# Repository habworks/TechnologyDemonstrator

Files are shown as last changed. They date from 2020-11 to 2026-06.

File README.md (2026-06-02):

# Hab's Technology Demonstrator
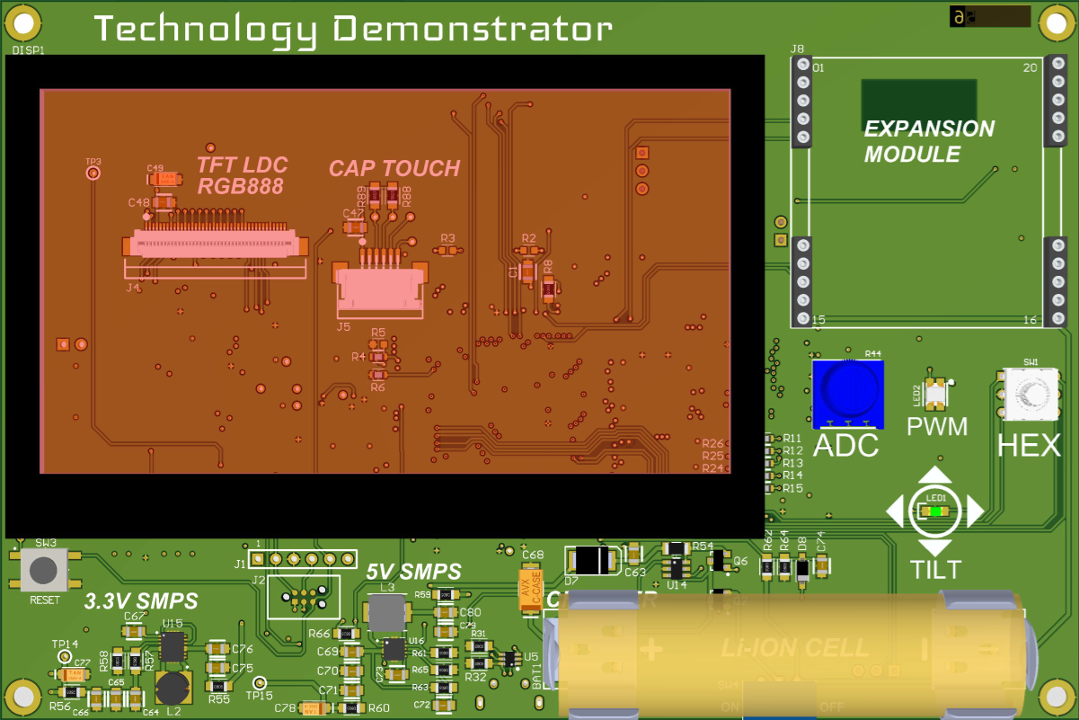
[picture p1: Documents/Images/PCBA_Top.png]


Developed as a sales tool to assist me in selling my design capabilites this is a catch-all project.  It includes a little of everything.  Based on an ARM Cortex M7 and the Touch GFX graphics library the project demonstrates my hardware and firmware design capabilites.  Devloped during the COVID lock-in I hope you enjoy it, see the value, and invite me to work on your project:<br>

## Quick Visual Links:
See [Block Diagram](https://imrengineeringcom-my.sharepoint.com/:p:/g/personal/hab_collector_imrengineering_com/IQBJmAEbv2q8TZ0ApIJ88drxAbf0ilMzcAGDfjFYzenVswI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) from IMR Cloud<br>
See [Schematics PCB 3D](https://imrengineeringcom-my.sharepoint.com/:b:/g/personal/hab_collector_imrengineering_com/IQCkbXLIxkKmTaa8k9nujfb7AQS4M2PV1brDCnOEc579SEw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) from IMR Cloud<br>

## Project Features:
Hardware:
- ARM Cortex M7 uC
- Grapical Touch Display 
- SDRAM
- ADC & DAC
- SMPS
- Accelerometer
- uSD
- Battery Power and charging
- I2C, SPI, USB, UART
 
Firmware:
- FreeRTOS + CMSIS
- Grpahical User Interface
- UI Touch Interface 242x480  
- Custom Audio Playback
- Custom Driver Development  
 
Hardware and Firmware 100% designed by:<br>
Hab Collector<br>
Principal Engineer<br>
IMR Engineering, LLC<br>

## Project Folders:
| Folder | Description |
|---|---|
| Demo | URL to demo - just use the link provided above|
| Documents | Block Diagram and misc|
| AppFirmware/TD_AppFirmware| Application Firmware|
| AppFirmware/ESP8266| WIFI Module|
| Firmware| Test Firmware|
| Hardware | Hardware Design in Altium: Schematics, PCB, Gerber|

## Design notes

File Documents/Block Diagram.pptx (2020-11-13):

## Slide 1

MICRO SD DRIVE

D[0:3], CLK, CMD
SD DETECT

MEMORY

STM32F746I
MEMORY

SDRAM 4M X 32

A[0:11], D[0:15],
B[0:1], NBL[0:1],
SDCKE0, SDCLK, SDNCAS,
SDNE0, SDRAS, SDNWE

D[0:3], CLK, CMD,

SD DETECT

ADDR, DATA, CTL

QUAD SPI FLASH

IO[0:3], CLK, NCS

IO[0:3], CLK, NCS

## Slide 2

LCD TOUCH

I2C#

LCD & TOUCH

STM32F746I
LCD & TOUCH

TFT LCD RGB888

RED[0:7]
GREEN[0:7]
BLUE[0:7]
CLK
DE
VSYNC
HSYNC

SDA, SCLK

IRQ, RESET

R, G, B, CTL

BACK LIGHT PWM

DISPLAY ON /OFF

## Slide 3

USB OTG FS

DP, DM
VBUS, SOF, ID, PWR

USB & SERIAL

STM32F746I
USB
SERIAL

UART: WIFI ESP8266

UART#

DP, DM

VBUS, SOF, ID, PWR

TX, RX

UART: DEBUG

UART#

UART: EXPANSION

UART#

TX, RX

TX, RX

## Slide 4

AUDIO VOL TRIM POT

I2C#

I2C & SPI

STM32F746I
I2C
SPI

EXPANSION SLOT

I2C#

SDA, SCLK

SDA, SCLK

ACCELEROMETER

SPI#

EXPANSION SLOT

SPI#

MOSI, MISO, CLK

MOSI, MISO, CLK

CS

CS

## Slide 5

ANALOG SIGNALS

ADC#: BATTERY
ADC#: UI GUI

ADC DAC GPIO

ADC
DAC
GPIO

ADC

ULTRA SONIC

PWR, TRIG, ECHO

AUDIO OUT

AUDIO CIRCUIT

IO

DAC

UI INTERACTIVE

UI LED
UI SWITCH

EXPANSION SLOT

GPIO

GPIO

GPIO

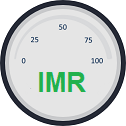
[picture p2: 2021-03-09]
AppFirmware/TD_AppFirmware/TouchGFX/assets/images/IMR_Engineering_Guage.png

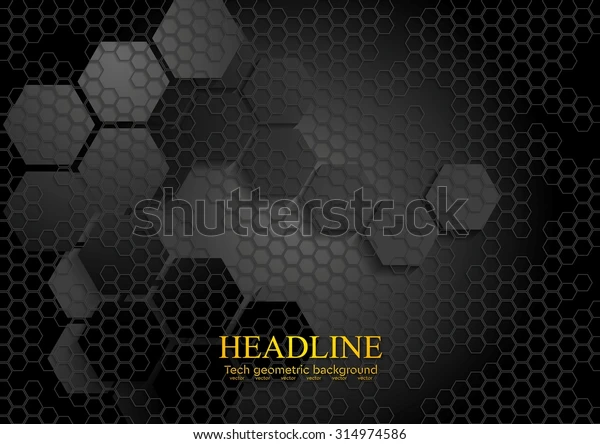
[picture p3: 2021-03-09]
AppFirmware/TD_AppFirmware/TouchGFX/assets/images/Background2.png

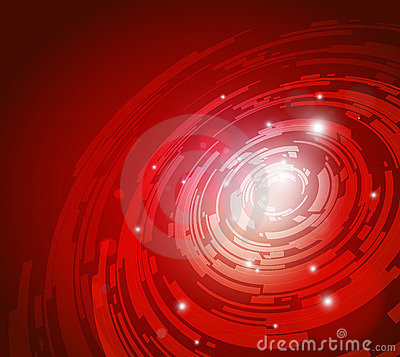
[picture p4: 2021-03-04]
AppFirmware/TD_AppFirmware/TouchGFX/assets/images/DigitalRed3.png

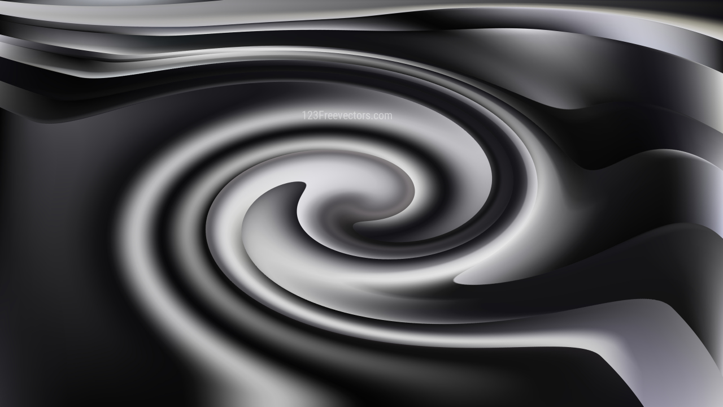
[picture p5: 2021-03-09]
AppFirmware/TD_AppFirmware/TouchGFX/assets/images/Background1.png

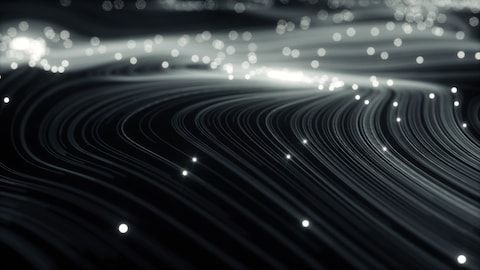
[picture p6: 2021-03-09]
AppFirmware/TD_AppFirmware/TouchGFX/assets/images/MainMenuBG.png

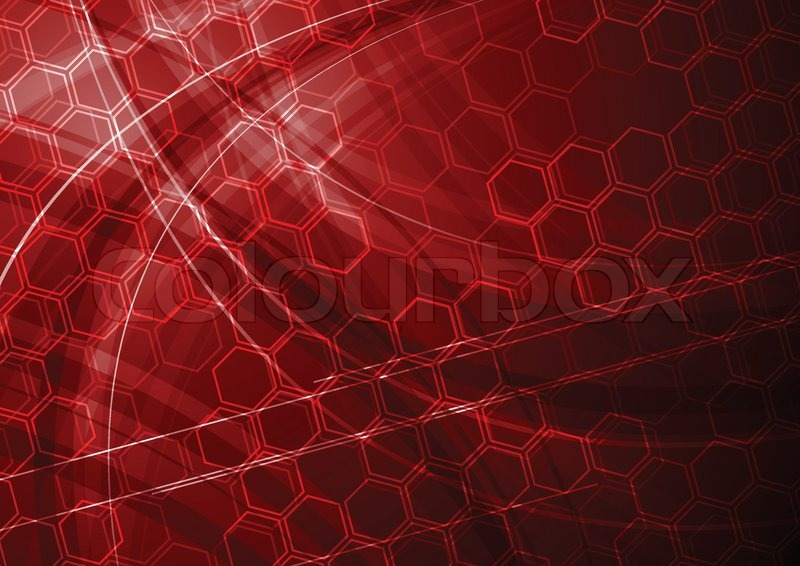
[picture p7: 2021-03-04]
AppFirmware/TD_AppFirmware/TouchGFX/assets/images/DigitalRed2.png

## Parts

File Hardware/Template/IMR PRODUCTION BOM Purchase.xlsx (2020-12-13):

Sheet: Part List Report
 |  | PRODUCTION BOM |  |  | Field=ProjectTitle
 |  | Source Data From: | Field=DataSourceFileName |  | Company Part Number: | Field=DocumentNumber
 |  | Project: | Field=ProjectFileName |  | PCB Revision: | Field=Revision
 |  | Variant: | Field=VariantName |  | Engineer: | Field=Engineer
 |  | Report Date: | Field=ReportDate | Field=ReportTime
 |  | Print Date: | 2020-12-12 | 6:47:49
# | Column=Quantity | Column=LibRef | Column=Description | Column=Designator | Column=MFG | Column=MFG_PN | Column=Supplier 1 | Column=Supplier Part Number 1 | Column=Footprint
1
2
3
Approved |  |  |  |  | Notes |  |  | Total Items in BOM | Field=TotalQuantity

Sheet: Project Information
Project Full Path | Field=ProjectFullPath
Project Filename | Field=ProjectFileName
Variant Name | Field=VariantName
Data-Source Filename | Field=DataSourceFileName
Data-Source Full Path | Field=DataSourceFullPath
Title | Field=Title
Total Quantity | Field=TotalQuantity
Report Time | Field=ReportTime
Report Date | Field=ReportDate
Report Date & Tine | Field=ReportDateTime
Output Name | Field=OutputName
Output Type | Field=OutputType
Output Generator Name | Field=GeneratorName
Output Generator Description | Field=GeneratorDescription
Total Actual Price | Field=TotalActualPrice
Total Target Price | Field=TotalTargetPrice

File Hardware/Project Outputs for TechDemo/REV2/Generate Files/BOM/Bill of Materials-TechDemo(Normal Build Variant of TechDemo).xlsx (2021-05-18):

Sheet: Part List Report
 |  | PRODUCTION BOM |  |  | IMR Technology Demonstrator
 |  | Source Data From: | TechDemo.PrjPcb |  | Company Part Number: | IMR_004
 |  | Project: | TechDemo.PrjPcb |  | PCB Revision: | 2
 |  | Variant: | Normal Build Variant of TechDemo |  | Engineer: | H. Collector
 |  | Report Date: | 4/17/2021 | 1:39 PM
 |  | Print Date: | 2021-04-17 | 13:39:05
# | Quantity | LibRef | Description | Designator | MFG | MFG_PN | Supplier 1 | Supplier Part Number 1 | Footprint
1 | 1 | CONN_BATTERY_18650 | BATTERY CONTACT CLP 18650 PC PIN (NOTE: QTY x2) | BAT1 | Keystone Electronics | 54 | Digi-Key | 36-54-ND | CONN_BATTERY_18650
2 | 13 | CAP_2.2UF_50V_0805 | CAP CER 2.2UF 50V X7R 0805 | C1, C22, C23, C24, C25, C26, C27, C28, C29, C61, C62, C63, C74 | Taiyo Yuden | UMK212BB7225MG-T | Digi-Key | 587-4963-1-ND | CAP_0805
3 | 2 | CAP_4.7PF_50V_0603 | CAP CER 4.7PF 50V C0G/NPO 0603 | C4, C5 | Yageo | CC0603CRNPO9BN4R7 | Digi-Key | 311-1740-1-ND | CAP_0603
4 | 28 | CAP_0.1UF_50V_0603 | CAP CER 0.1UF 50V X7R 0603 | C6, C7, C8, C9, C10, C11, C12, C13, C14, C15, C16, C17, C18, C19, C20, C21, C32, C33, C34, C35, C36, C37, C38, C39, C40, C41, C42, C43 | Yageo | CC0603KRX7R9BB104 | Digi-Key | 311-1344-1-ND | CAP_0603
5 | 18 | CAP_0.1UF_50V_0805 | CAP CER 0.1UF 50V X7R 0805 | C30, C31, C47, C48, C50, C51, C52, C53, C56, C57, C58, C60, C67, C81, C82, C83, C86, C87 | AVX | 08055C104KAT2A | Digi-Key | 478-1395-1-ND | CAP_0805
6 | 4 | CAP_10UF_10V_0805 | CAP CER 10UF 10V X7R 0805 | C44, C45, C76, C80 | TDK Corporation | C2012X7R1A106K125AC | Digi-Key | 445-6857-1-ND | CAP_0805
7 | 4 | CAP_22UF_10V_TANT | CAP TANT 22UF 20% 10V 1206 | C46, C49, C77, C78 | AVX Corporation | TAJA226M010RNJ | Digi-Key | 478-5798-1-ND | CAP_1206_TANT
8 | 3 | CAP_10UF_50V_1206 | CAP CER 10UF 50V X5R 1206 | C54, C84, C85 | Samsung Electro-Mechanics | CL31A106KBHNNNE | Digi-Key | 1276-2876-1-ND | CAP_1206
9 | 1 | CAP_1.0UF_50V_0805 | CAP CER 1UF 50V X7R 0805 | C55 | Taiyo Yuden | UMK212B7105MGHT | Digi-Key | 587-6375-1-ND | CAP_0805
10 | 3 | CAP_22UF_16V_TANT | CAP TANT 22UF 20% 16V 2312, CAP TANT 22UF 10% 16V 2312 | C59, C68, C88 | AVX Corporation | TRJC226K016RRJ | Digi-Key | 478-11127-1-ND | CAP_2312
11 | 8 | CAP_22UF_6.3V_0805 | CAP CER 22UF 6.3V X5R 0805 | C64, C65, C66, C69, C70, C71, C75, C79 | Samsung Electro-Mechanics | CL21A226KQQNNNE | Digi-Key | 1276-2907-1-ND | CAP_0805
12 | 1 | CAP_18PF_50V_0805 | CAP CER 18PF 50V C0G/NP0 0805 | C72 | Stackpole Electronics Inc | CML0805C0G180JT50V | Digi-Key | 738-CML0805C0G180JT50VCT-ND | CAP_0805
13 | 1 | CAP_18NF_50V_0805 | CAP CER 0.018UF 50V X7R 0805 | C73 | Yageo | CC0805KRX7R9BB183 | Digi-Key | 311-1137-1-ND | CAP_0805
14 | 5 | DIODE_1N4148W-7-F | DIODE GEN PURP 100V 300MA SOD123 | D1, D5, D6, D8, D10 | Diodes Incorporated | 1N4148W-7-F | Digi-Key | 1N4148W-FDICT-ND | SOD123
15 | 2 | DIODE_SCHOTTKY_PMEG3005EGWJ | DIODE SCHOTTKY 30V 500MA SOD123 | D2, D9 | Nexperia USA Inc. | PMEG3005EGWJ | Digi-Key | MBRS2040LT3GOSCT-ND | SOD123
16 | 2 | DIODE_TVS_GSOT03C-G3-08 | TVS DIODE 3.3V 12.3V SOT23 | D3, D4 | Vishay Semiconductor | GSOT03C-G3-08 | Digi-Key | GSOT03C-G3-08GICT-ND | SOT-23
17 | 1 | DIODE_SCHOTTKY_MBRS2040LT3G | DIODE SCHOTTKY 40V 2A SMB | D7 | ON SEMICONDUCTOR | MBRS2040LT3G | Digi-Key | MBRS2040LT3GOSCT-ND | SMB
18 | 1 | MODULE_NHD-4.3-480272EF-ASXV#-CTP | LCD TFT 480X272 HIGH BRIGHT | DISP1 | Newhaven Display Intl | NHD-4.3-480272EF-ASXV#-CTP | DigiKey | NHD-4.3-480272EF-ASXV#-CTP-ND | NHD_NHD-4.3-480272EF-ASXV#-CTP
19 | 5 | FERRITE_BLM21AG102SN1D | FERRITE, 1KOHM AT 100MHZ, 220MA, .450DCR | FB1, FB2, FB3, FB4, FB5 | MURATA | BLM21AG102SN1D | Digi-Key | 490-1041-1-ND | RES_0805
20 | 1 | CONN_HIROSE_DM3BT-DSF-PEJS | CONN MICRO SD CARD PUSH-PUSH R/A | J3 | Hirose Electric Co Ltd | DM3BT-DSF-PEJS | Digi-Key | HR1942CT-ND | HRS_DM3BT-DSF-PEJS
21 | 1 | CONN_MOLEX_0512964033 | CONN FFC BOTTOM 40POS 0.50MM R/A | J4 | Molex | 0512964033 | Digi-Key | WM11237CT-ND | CONN_MOLEX_0512964033
22 | 1 | CONN_MOLEX_0522070660 | CONN FPC TOP 6POS 1.00MM R/A | J5 | Molex | 0522070660 | Digi-Key | WM10939CT-ND | CONN_MOLEX_0522070660
23 | 1 | CONN_USB_MOLEX_0475900001 | CONN RCPT MICRO USB AB 5P SMD RA | J6 | Molex | 0475900001 | Digi-Key | WM17144CT-ND | MICRO_USB_AB_MOLEX_0475900001
24 | 2 | CONN_3P_SINGLE_ROW | CONN HEADER VERT 3POS 2.54MM | J7, J11 | Sullins Connector Solutions | PREC003SFAN-RC | Digi-Key | S1212EC-03-ND | HDR_1X3_100MILL
25 | 1 | CONN_TD_EXPANSION_MODULE | CONN HEADER VERT 5POS 2.54MM (NOTE: QTY x4) | J8 | Sullins Connector Solutions | PPTC051LFBN-RC | Digi-Key | S6103-ND | CONN_EXPANSION_BOARD
26 | 1 | CONN_2P_SINGLE_ROW | CONN HEADER VERT 2POS 2.54MM | J10 | Sullins Connector Solutions | PREC002SFAN-RC | Digi-Key | S1212EC-02-ND | HDR_1X2_100MILL
27 | 1 | INDUCTOR_LPS4018-472MRC | SHIELDED POWER INDUCTORS, 4.7UH | L1 | COILCRAFT | LPS4018-472MRC | Digi-Key | 2457-LPS4018-472MRC-ND | LPS4018
28 | 1 | INDUCTOR_SDR0403-1R0ML | FIXED IND 1UH 3.8A 33 MOHM SMD | L2 | Bourns Inc. | SDR0403-1R0ML | Digi-Key | SDR0403-1R0MLCT-ND | IND_SDR0403
29 | 1 | INDUCTOR_IHLP2020BZER1R0M01 | FIXED IND 1UH 3.8A 33 MOHM SMD | L3 | Bourns Inc. | IHLP2020BZER1R0M01 | Digi-Key | 541-1087-1-ND | INDPM5552X200N
30 | 1 | DIODE_LED_GREEN_LTST-C170GKT | DIODE, LED GREEN CLEAR SMD | LED1 | Lite-On Inc. | LTST-C170GKT | Digi-Key | 160-1179-1-ND | PMG_LTST-C170GKT
31 | 1 | LED_RED_GREEN_HSMF-A201-A00J1 | LED GREEN/RED CLEAR 4PLCC SMD | LED2 | Broadcom Limited | HSMF-A201-A00J1 | Digi-Key | 516-2491-1-ND | 4PLCC-LED
32 | 3 | MOSFET_PCH_NTR3A30PZT1G | MOSFET P-CH 20V 3A SOT23-3 | Q1, Q2, Q6 | ON Semiconductor | NTR3A30PZT1G | Digi-Key | NTR3A30PZT1GOSCT-ND | SOT-23
33 | 3 | MOSFET_NCH_2N7002-7-F | MOSFET N-CH 60V 115MA SOT23-3 | Q3, Q4, Q5 | Diodes Incorporated | 2N7002-7-F | Digi-Key | 2N7002-FDICT-ND | SOT-23
34 | 1 | RES_200_0805_1/8W_1%_1 | RES SMD 200 OHM 1% 1/8W 0805 | R1 | Yageo | RC0805FR-07200RL | Digi-Key | 311-200CRCT-ND | RES_0805
35 | 1 | RES_10K_0603_1/10W_1% | RES SMD 10K OHM 1% 1/10W 0603 | R4 | Yageo | RC0603FR-0710KL | Digi-Key | 311-10.0KHRCT-ND | RES_0603
36 | 20 | RES_100K_0603_1/10W_1% | RES SMD 100K OHM 1% 1/10W 0603 | R6, R7, R11, R12, R13, R14, R15, R16, R17, R18, R19, R20, R21, R22, R23, R24, R25, R26, R67, R68 | Yageo | RC0603FR-07100KL | Digi-Key | 311-100KHRCT-ND | RES_0603
37 | 10 | RES_0_0805_1/8W | RES SMD 0 OHM JUMPER 1/8W 0805 | R8, R29, R30, R33, R52, R55, R56, R59, R60, R76 | Yageo | RC0805JR-070RL | Digi-Key | 311-0.0ARCT-ND | PMG_RES_0805
38 | 13 | RES_10K_0805_1/4W_1% | RES SMD 10K OHM 1% 1/4W 0805 | R9, R10, R45, R47, R49, R69, R70, R71, R72, R73, R78, R88, R89 | KOA Speer Electronics, Inc. | SG73S2ATTD1002F | Digi-Key | 2019-SG73S2ATTD1002FCT-ND | RES_0805
39 | 24 | RES_100K_0805_1/4W_1% | RES SMD 100K OHM 1% 1/4W 0805 | R27, R34, R35, R36, R37, R40, R41, R42, R43, R46, R48, R50, R51, R61, R64, R65, R66, R74, R75, R79, R80, R81, R82, R85 | KOA Speer Electronics, Inc. | RK73H2ATTD1003F | Digi-Key | 2019-RK73H2ATTD1003FCT-ND | PMG_RES_0805
40 | 1 | RES_5.1_0805_1/8W_1% | RES 5.1 OHM 1% 1/8W 0805 | R28 | Yageo | RC0805FR-075R1L | Digi-Key | YAG3373CT-ND | PMG_RES_0805
41 | 2 | RES_15K_0805_1/8W_1% | RES SMD 15K OHM 1% 1/8W 0805 | R31, R32 | Yageo | RC0805FR-0715KL | Digi-Key | 311-15.0KCRCT-ND | RES_0805
42 | 2 | RES_120_0805_1/4W_1% | RES 120 OHM 1% 1/4W 0805 | R38, R39 | KOA Speer Electronics, Inc. | RK73H2ATTD1200F | Digi-Key | 2019-RK73H2ATTD1200FCT-ND | PMG_RES_0805
43 | 1 | RES_POT_10K_500mW | TRIMMER 10K OHM 0.5W PC PIN TOP | R44 | Bourns Inc. | 3386F-1-103TLF | Digi-Key | 3386F-103TLF-ND | BOURNS_3386F
44 | 1 | RES_1K_0805_1/8W_1% | RES SMD 1K OHM 1% 1/8W 0805 | R53 | Yageo | RC0805FR-071KL | Digi-Key | 311-1.00KCRCT-ND | RES_0805
45 | 1 | RES_0.140_1206_1/4W_1% | RES 0.14 OHM 1% 1/4W 1206 | R54 | Yageo | RL1206FR-070R14L | Digi-Key | 311-.14LWCT-ND | 1206
46 | 1 | RES_768K_0805_1/8W_1% | RES SMD 768K OHM 1% 1/8W 0805 | R57 | Yageo | RC0805FR-07768KL | Digi-Key | 311-768KCRCT-ND | PMG_RES_0805
47 | 1 | RES_137K_0805_1/8W_1% | RES SMD 137K OHM 1% 1/8W 0805 | R58 | Yageo | RC0805FR-07137KL | Digi-Key | 311-137KCRCT-ND | PMG_RES_0805
48 | 1 | RES_40.2K_0805_1/8W_1%_1 | RES SMD 40.2K OHM 1% 1/8W 0805 | R62 | Yageo | RC0805FR-0740K2L | Digi-Key | 311-40.2KCRCT-ND | RES_0805
49 | 1 | RES_383K_0805_1/8W_1% | RES SMD 383K OHM 1% 1/8W 0805 | R63 | Yageo | RC0805FR-07383KL | Digi-Key | 311-383KCRCT-ND | RES_0805
50 | 2 | RES_20K_0805_1/8W_1% | RES SMD 20K OHM 1% 1/8W 0805 | R83, R84 | Yageo | RC0805FR-0720KL | Digi-Key | 311-20.0KCRCT-ND | RES_0805
51 | 2 | RES_30K_0805_1/8W_1% | RES SMD 30K OHM 1% 1/8W 0805 | R86, R87 | Panasonic Electronic Components | ERJ-6ENF3002V | Digi-Key | P30.0KCCT-ND | RES_0805
52 | 1 | SW_DIP_220ADC16 | SWITCH ROTARY DIP HEX 100MA 50V | SW1 | CTS Electrocomponents | 220ADC16 | DigiKey | CT3070-ND | CTS_220ADC16
53 | 3 | SWITCH_EVQ-Q2U02W | SWITCH TACTILE SPST-NO 0.02A 15V | SW2, SW3, SW5 | Panasonic Electronic Components | EVQ-Q2U02W | Digi-Key | P12954SCT-ND | SW_EVQ-Q2U02W
54 | 1 | SWITCH_450302014072 | SWITCH MINI SLIDE RA 2.54mm | SW4 | Wurth Elektronik | 450302014072 | Mouser | 710-450302014072 | SWITCH_WURTH_450302014072
55 | 1 | IC_STM32F746NGH6U | STM32F746NGH6 (STM32F7 Birdie) TBGA216 | U1 | STMicroelectronics | STM32F746IGT6 | DigiKey | 497-15817-ND | QFP50P2600X2600X160-176N
56 | 1 | IC_ IS42S32400F-6TL | IC DRAM 128M PARALLEL 86TSOP II | U2 | ISSI, Integrated Silicon Solution Inc | IS42S32400F-6TL-TR | Mouser | 870-IS42S32400F-6TL | 86TSOPII
57 | 1 | IC_MT25QL128ABA1ESE-0SIT | IC FLASH 128M SPI 133MHZ 8SOP2 | U3 | Micron Technology Inc. | MT25QL128ABA1ESE-0SIT | Digi-Key | 557-1772-1-ND | SO8W
58 | 1 | IC_TPS61169DCKR | IC LED DRVR RGLTR DIM 1.8A SC70 | U4 | Texas Instruments | TPS61169DCKR | Digi-Key | 296-40821-1-ND | SC70-5_SOT-353_5-TSSOP
59 | 1 | IC_RCLAMP0504FATCT | TVS DIODE 5V 25V SC70-6 | U5 | Semtech Corporation | RCLAMP0504FATCT | Digi-Key | RCLAMP0504FATCTCT-ND | SOT-363_6-TSSOP_SC-88
60 | 1 | IC_STMPS2141MTR | IC PWR SWITCH N-CHANNEL 1:1 8SO | U6 | STMicroelectronics | STMPS2141MTR | Digi-Key | 497-6932-1-ND | SO-8
61 | 1 | IC_LIS3DHTR | ACCEL 2-16G I2C/SPI 16LGA | U7 | STMicroelectronics | LIS3DHTR | Digi-Key | 497-10613-1-ND | XDCR_LIS3DHTR
62 | 1 | MODULE_RCWL-1601 | MODULE ULTRASONIC SENSOR 3V | U8 | Adafruit Industries LLC | 4007 | Digi-Key | 1528-2832-ND | 4007
63 | 1 | IC_TPL0401A-10DCKR | IC DGTL POT 10KOHM 128TAP SC70-6 | U9 | Texas Instruments | TPL0401A-10DCKR | Digi-Key | 296-29676-1-ND | SOT-363_6-TSSOP_SC-88
64 | 1 | IC_OPAMP_TSV620ILT | IC OPAMP GP 1 CIRCUIT SOT23-6 | U10 | STMicroelectronics | TSV620ILT | Digi-Key | 497-10160-1-ND | SOT23-6
65 | 1 | IC_OPAMP_LM4861 | IC AMP CLASS AB MONO 1.5W 8SOIC | U11 | Texas Instruments | LM4861MX/NOPB | Digi-Key | 296-38566-1-ND | SO-8
66 | 1 | IC_NX3DV221TKX | IC USB 2.0 SWITCH HS 10HVSON | U12 | NXP USA Inc. | NX3DV221TKX | Digi-Key | 568-10368-1-ND | PMG_NX3DV221TKX
67 | 1 | MODULE_2491 | RX TXRX MOD WIFI TRACE ANT SMD 4MB | U13 | Adafruit Industries LLC | 2491 | Digi-Key | 1528-1438-ND | XCVR_ESP8266-12E/ESP-12E
68 | 1 | IC_MCP73826-4.1VCHTR | IC CONTROLLR LI-ION 4.1V SOT23-6 | U14 | Microchip Technology | MCP73826-4.1VCHTR | Digi-Key | MCP73826-4.1VCHCT-ND | SOT23-6
69 | 1 | IC_TPS63020DSJR | IC REG BCK BST ADJ 3.5A 14VSON | U15 | Texas Instruments | TPS63020DSJR | Digi-Key | 296-36491-1-ND | 14VSON
70 | 1 | IC_TPS61230DRCR | IC REG BOOST ADJ 4A 10VSON | U16 | Texas Instruments | TPS61230DRCR | Digi-Key | 296-37761-1-ND | 10VSON
71 | 1 | IC_LDS3985M33R | IC REG LINEAR 3.3V 300MA SOT23-5 | U17 | STMicroelectronics | LDS3985M33R | Digi-Key | 497-4257-1-ND | SOT23-5
72 | 1 | IC_COMPARATOR_MCP6546T-I/SN | IC COMP OPENDRN 1.6V SNGL 8-SOIC | U18 | Microchip Technology | MCP6546T-I/SN | Digi-Key | MCP6546T-I/SNCT-ND | SO-8
73 | 1 | IC_OSC_ECS-2520MVLC-250-BN-TR | XTAL OSC XO 25MHZ CMOS SMD | X1 | ECS Inc. | ECS-2520MVLC-250-BN-TR | Digi-Key | 50-ECS-2520MVLC-250-BN-CT-ND | OSC_ECS-2520S25-250-FN-TR
74 | 1 | XTAL_32.768KHZ_6PF_SMD | CRYSTAL 32.7680KHZ 6PF SMD | X3 | EPSON | MC-306 32.7680K-E0:PURE SN | Digi-Key | SER4097CT-ND | XTAL_ECS-.327-6-17X-TR
Approved |  |  |  |  | Notes |  |  | Total Items in BOM | 232

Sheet: Project Information
Project Full Path | C:\IMR_Projects\HabProjects\TechDemo\Hardware\TechDemo.PrjPcb
Project Filename | TechDemo.PrjPcb
Variant Name | Normal Build Variant of TechDemo
Data-Source Filename | TechDemo.PrjPcb
Data-Source Full Path | C:\IMR_Projects\HabProjects\TechDemo\Hardware\TechDemo.PrjPcb
Title | Bill of Materials for Variant [Normal Build Variant of TechDemo] of Project [TechDemo.PrjPcb] (No PCB Document Selected)
Total Quantity | 232
Report Time | 1:39 PM
Report Date | 4/17/2021
Report Date & Tine | 4/17/2021 1:39 PM
Output Name | Bill of Materials
Output Type | BOM_PartType
Output Generator Name | BOM
Output Generator Description | Bill of Materials
Total Actual Price | <Parameter TotalActualPrice not found>
Total Target Price | <Parameter TotalTargetPrice not found>

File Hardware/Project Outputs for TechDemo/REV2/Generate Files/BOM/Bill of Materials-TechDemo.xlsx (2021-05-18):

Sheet: Part List Report
 |  | PRODUCTION BOM |  |  | IMR Technology Demonstrator
 |  | Source Data From: | TechDemo.PrjPcb |  | Company Part Number: | IMR_004
 |  | Project: | TechDemo.PrjPcb |  | PCB Revision: | 2
 |  | Variant: | None |  | Engineer: | H. Collector
 |  | Report Date: | 4/16/2021 | 9:34 AM
 |  | Print Date: | 2021-04-16 | 9:34:55
# | Quantity | LibRef | Description | Designator | MFG | MFG_PN | Supplier 1 | Supplier Part Number 1 | Footprint
1 | 1 | CONN_BATTERY_18650 | BATTERY CONTACT CLP 18650 PC PIN (NOTE: QTY x2) | BAT1 | Keystone Electronics | 54 | Digi-Key | 36-54-ND | CONN_BATTERY_18650
2 | 14 | CAP_2.2UF_50V_0805 | CAP CER 2.2UF 50V X7R 0805 | C1, C22, C23, C24, C25, C26, C27, C28, C29, C54, C61, C62, C63, C74 | Taiyo Yuden | UMK212BB7225MG-T | Digi-Key | 587-4963-1-ND | CAP_0805
3 | 2 | CAP_27PF_50V_0603 | CAP CER 4.7PF 50V C0G/NPO 0603 | C2, C3 | Yageo | CC0603KRNPO9BN270 | Digi-Key | 311-4032-1-ND | CAP_0603
4 | 2 | CAP_4.7PF_50V_0603 | CAP CER 4.7PF 50V C0G/NPO 0603 | C4, C5 | Yageo | CC0603CRNPO9BN4R7 | Digi-Key | 311-1740-1-ND | CAP_0603
5 | 28 | CAP_0.1UF_50V_0603 | CAP CER 0.1UF 50V X7R 0603 | C6, C7, C8, C9, C10, C11, C12, C13, C14, C15, C16, C17, C18, C19, C20, C21, C32, C33, C34, C35, C36, C37, C38, C39, C40, C41, C42, C43 | Yageo | CC0603KRX7R9BB104 | Digi-Key | 311-1344-1-ND | CAP_0603
6 | 18 | CAP_0.1UF_50V_0805 | CAP CER 0.1UF 50V X7R 0805 | C30, C31, C47, C48, C50, C51, C52, C53, C56, C57, C58, C60, C67, C81, C82, C83, C86, C87 | AVX | 08055C104KAT2A | Digi-Key | 478-1395-1-ND | CAP_0805
7 | 4 | CAP_10UF_10V_0805 | CAP CER 10UF 10V X7R 0805 | C44, C45, C76, C80 | TDK Corporation | C2012X7R1A106K125AC | Digi-Key | 445-6857-1-ND | CAP_0805
8 | 4 | CAP_22UF_10V_TANT | CAP TANT 22UF 20% 10V 1206 | C46, C49, C77, C78 | AVX Corporation | TAJA226M010RNJ | Digi-Key | 478-5798-1-ND | CAP_1206_TANT
9 | 1 | CAP_1.0UF_50V_0805 | CAP CER 1UF 50V X7R 0805 | C55 | Taiyo Yuden | UMK212B7105MGHT | Digi-Key | 587-6375-1-ND | CAP_0805
10 | 3 | CAP_22UF_16V_TANT | CAP TANT 22UF 20% 16V 2312, CAP TANT 22UF 10% 16V 2312 | C59, C68, C88 | AVX Corporation | TRJC226K016RRJ | Digi-Key | 478-11127-1-ND | CAP_2312
11 | 8 | CAP_22UF_6.3V_0805 | CAP CER 22UF 6.3V X5R 0805 | C64, C65, C66, C69, C70, C71, C75, C79 | Samsung Electro-Mechanics | CL21A226KQQNNNE | Digi-Key | 1276-2907-1-ND | CAP_0805
12 | 1 | CAP_18PF_50V_0805 | CAP CER 18PF 50V C0G/NP0 0805 | C72 | Stackpole Electronics Inc | CML0805C0G180JT50V | Digi-Key | 738-CML0805C0G180JT50VCT-ND | CAP_0805
13 | 1 | CAP_18NF_50V_0805 | CAP CER 0.018UF 50V X7R 0805 | C73 | Yageo | CC0805KRX7R9BB183 | Digi-Key | 311-1137-1-ND | CAP_0805
14 | 2 | CAP_10UF_50V_1206 | CAP CER 10UF 50V X5R 1206 | C84, C85 | Samsung Electro-Mechanics | CL31A106KBHNNNE | Digi-Key | 1276-2876-1-ND | CAP_1206
15 | 5 | DIODE_1N4148W-7-F | DIODE GEN PURP 100V 300MA SOD123 | D1, D5, D6, D8, D10 | Diodes Incorporated | 1N4148W-7-F | Digi-Key | 1N4148W-FDICT-ND | SOD123
16 | 2 | DIODE_SCHOTTKY_PMEG3005EGWJ | DIODE SCHOTTKY 30V 500MA SOD123 | D2, D9 | Nexperia USA Inc. | PMEG3005EGWJ | Digi-Key | MBRS2040LT3GOSCT-ND | SOD123
17 | 2 | DIODE_TVS_GSOT03C-G3-08 | TVS DIODE 3.3V 12.3V SOT23 | D3, D4 | Vishay Semiconductor | GSOT03C-G3-08 | Digi-Key | GSOT03C-G3-08GICT-ND | SOT-23
18 | 1 | DIODE_SCHOTTKY_MBRS2040LT3G | DIODE SCHOTTKY 40V 2A SMB | D7 | ON SEMICONDUCTOR | MBRS2040LT3G | Digi-Key | MBRS2040LT3GOSCT-ND | SMB
19 | 1 | MODULE_NHD-4.3-480272EF-ASXV#-CTP | LCD TFT 480X272 HIGH BRIGHT | DISP1 | Newhaven Display Intl | NHD-4.3-480272EF-ASXV#-CTP | DigiKey | NHD-4.3-480272EF-ASXV#-CTP-ND | NHD_NHD-4.3-480272EF-ASXV#-CTP
20 | 5 | FERRITE_BLM21AG102SN1D | FERRITE, 1KOHM AT 100MHZ, 220MA, .450DCR | FB1, FB2, FB3, FB4, FB5 | MURATA | BLM21AG102SN1D | Digi-Key | 490-1041-1-ND | RES_0805
21 | 1 | CONN_6P_SINGLE_ROW | CONN HEADER VERT 6POS 2.54MM | J1 | Sullins Connector Solutions | PREC006SFAN-RC | Digi-Key | S1212EC-06-ND | HDR_1X6_100MILL
22 | 1 | CONN_HIROSE_DM3BT-DSF-PEJS | CONN MICRO SD CARD PUSH-PUSH R/A | J3 | Hirose Electric Co Ltd | DM3BT-DSF-PEJS | Digi-Key | HR1942CT-ND | HRS_DM3BT-DSF-PEJS
23 | 1 | CONN_MOLEX_0512964033 | CONN FFC BOTTOM 40POS 0.50MM R/A | J4 | Molex | 0512964033 | Digi-Key | WM11237CT-ND | CONN_MOLEX_0512964033
24 | 1 | CONN_MOLEX_0522070660 | CONN FPC TOP 6POS 1.00MM R/A | J5 | Molex | 0522070660 | Digi-Key | WM10939CT-ND | CONN_MOLEX_0522070660
25 | 1 | CONN_USB_MOLEX_0475900001 | CONN RCPT MICRO USB AB 5P SMD RA | J6 | Molex | 0475900001 | Digi-Key | WM17144CT-ND | MICRO_USB_AB_MOLEX_0475900001
26 | 2 | CONN_3P_SINGLE_ROW | CONN HEADER VERT 3POS 2.54MM | J7, J11 | Sullins Connector Solutions | PREC003SFAN-RC | Digi-Key | S1212EC-03-ND | HDR_1X3_100MILL
27 | 1 | CONN_TD_EXPANSION_MODULE | CONN HEADER VERT 5POS 2.54MM (NOTE: QTY x4) | J8 | Sullins Connector Solutions | PPTC051LFBN-RC | Digi-Key | S6103-ND | CONN_EXPANSION_BOARD
28 | 2 | CONN_2P_SINGLE_ROW | CONN HEADER VERT 2POS 2.54MM | J9, J10 | Sullins Connector Solutions | PREC002SFAN-RC | Digi-Key | S1212EC-02-ND | HDR_1X2_100MILL
29 | 1 | INDUCTOR_LPS4018-472MRC | SHIELDED POWER INDUCTORS, 4.7UH | L1 | COILCRAFT | LPS4018-472MRC | Digi-Key | 2457-LPS4018-472MRC-ND | LPS4018
30 | 2 | INDUCTOR_SDR0403-1R0ML | FIXED IND 1UH 3.8A 33 MOHM SMD | L2, L4 | Bourns Inc. | SDR0403-1R0ML | Digi-Key | SDR0403-1R0MLCT-ND | IND_SDR0403
31 | 1 | INDUCTOR_IHLP2020BZER1R0M01 | FIXED IND 1UH 3.8A 33 MOHM SMD | L3 | Bourns Inc. | IHLP2020BZER1R0M01 | Digi-Key | 541-1087-1-ND | INDPM5552X200N
32 | 1 | DIODE_LED_GREEN_LTST-C170GKT | DIODE, LED GREEN CLEAR SMD | LED1 | Lite-On Inc. | LTST-C170GKT | Digi-Key | 160-1179-1-ND | PMG_LTST-C170GKT
33 | 1 | LED_RED_GREEN_HSMF-A201-A00J1 | LED GREEN/RED CLEAR 4PLCC SMD | LED2 | Broadcom Limited | HSMF-A201-A00J1 | Digi-Key | 516-2491-1-ND | 4PLCC-LED
34 | 3 | MOSFET_PCH_NTR3A30PZT1G | MOSFET P-CH 20V 3A SOT23-3 | Q1, Q2, Q6 | ON Semiconductor | NTR3A30PZT1G | Digi-Key | NTR3A30PZT1GOSCT-ND | SOT-23
35 | 3 | MOSFET_NCH_2N7002-7-F | MOSFET N-CH 60V 115MA SOT23-3 | Q3, Q4, Q5 | Diodes Incorporated | 2N7002-7-F | Digi-Key | 2N7002-FDICT-ND | SOT-23
36 | 1 | RES_200_0805_1/8W_1%_1 | RES SMD 200 OHM 1% 1/8W 0805 | R1 | Yageo | RC0805FR-07200RL | Digi-Key | 311-200CRCT-ND | RES_0805
37 | 2 | RES_1M_0603_1/10W_1% | RES SMD 1M OHM 1% 1/10W 0603 | R2, R3 | Yageo | RC0603FR-071ML | Digi-Key | 311-1.00MHRCT-ND | RES_0603
38 | 2 | RES_10K_0603_1/10W_1% | RES SMD 10K OHM 1% 1/10W 0603 | R4, R5 | Yageo | RC0603FR-0710KL | Digi-Key | 311-10.0KHRCT-ND | RES_0603
39 | 20 | RES_100K_0603_1/10W_1% | RES SMD 100K OHM 1% 1/10W 0603 | R6, R7, R11, R12, R13, R14, R15, R16, R17, R18, R19, R20, R21, R22, R23, R24, R25, R26, R67, R68 | Yageo | RC0603FR-07100KL | Digi-Key | 311-100KHRCT-ND | RES_0603
40 | 11 | RES_0_0805_1/8W | RES SMD 0 OHM JUMPER 1/8W 0805 | R8, R29, R30, R33, R52, R55, R56, R59, R60, R76, R77 | Yageo | RC0805JR-070RL | Digi-Key | 311-0.0ARCT-ND | PMG_RES_0805
41 | 13 | RES_10K_0805_1/4W_1% | RES SMD 10K OHM 1% 1/4W 0805 | R9, R10, R45, R47, R49, R69, R70, R71, R72, R73, R78, R88, R89 | KOA Speer Electronics, Inc. | SG73S2ATTD1002F | Digi-Key | 2019-SG73S2ATTD1002FCT-ND | RES_0805
42 | 24 | RES_100K_0805_1/4W_1% | RES SMD 100K OHM 1% 1/4W 0805 | R27, R34, R35, R36, R37, R40, R41, R42, R43, R46, R48, R50, R51, R61, R64, R65, R66, R74, R75, R79, R80, R81, R82, R85 | KOA Speer Electronics, Inc. | RK73H2ATTD1003F | Digi-Key | 2019-RK73H2ATTD1003FCT-ND | PMG_RES_0805
43 | 1 | RES_5.1_0805_1/8W_1% | RES 5.1 OHM 1% 1/8W 0805 | R28 | Yageo | RC0805FR-075R1L | Digi-Key | YAG3373CT-ND | PMG_RES_0805
44 | 2 | RES_15K_0805_1/8W_1% | RES SMD 15K OHM 1% 1/8W 0805 | R31, R32 | Yageo | RC0805FR-0715KL | Digi-Key | 311-15.0KCRCT-ND | RES_0805
45 | 2 | RES_120_0805_1/4W_1% | RES 120 OHM 1% 1/4W 0805 | R38, R39 | KOA Speer Electronics, Inc. | RK73H2ATTD1200F | Digi-Key | 2019-RK73H2ATTD1200FCT-ND | PMG_RES_0805
46 | 1 | RES_POT_10K_500mW | TRIMMER 10K OHM 0.5W PC PIN TOP | R44 | Bourns Inc. | 3386F-1-103TLF | Digi-Key | 3386F-103TLF-ND | BOURNS_3386F
47 | 1 | RES_1K_0805_1/8W_1% | RES SMD 1K OHM 1% 1/8W 0805 | R53 | Yageo | RC0805FR-071KL | Digi-Key | 311-1.00KCRCT-ND | RES_0805
48 | 1 | RES_0.140_1206_1/4W_1% | RES 0.14 OHM 1% 1/4W 1206 | R54 | Yageo | RL1206FR-070R14L | Digi-Key | 311-.14LWCT-ND | 1206
49 | 1 | RES_768K_0805_1/8W_1% | RES SMD 768K OHM 1% 1/8W 0805 | R57 | Yageo | RC0805FR-07768KL | Digi-Key | 311-768KCRCT-ND | PMG_RES_0805
50 | 1 | RES_137K_0805_1/8W_1% | RES SMD 137K OHM 1% 1/8W 0805 | R58 | Yageo | RC0805FR-07137KL | Digi-Key | 311-137KCRCT-ND | PMG_RES_0805
51 | 1 | RES_40.2K_0805_1/8W_1%_1 | RES SMD 40.2K OHM 1% 1/8W 0805 | R62 | Yageo | RC0805FR-0740K2L | Digi-Key | 311-40.2KCRCT-ND | RES_0805
52 | 1 | RES_383K_0805_1/8W_1% | RES SMD 383K OHM 1% 1/8W 0805 | R63 | Yageo | RC0805FR-07383KL | Digi-Key | 311-383KCRCT-ND | RES_0805
53 | 2 | RES_20K_0805_1/8W_1% | RES SMD 20K OHM 1% 1/8W 0805 | R83, R84 | Yageo | RC0805FR-0720KL | Digi-Key | 311-20.0KCRCT-ND | RES_0805
54 | 2 | RES_30K_0805_1/8W_1% | RES SMD 30K OHM 1% 1/8W 0805 | R86, R87 | Panasonic Electronic Components | ERJ-6ENF3002V | Digi-Key | P30.0KCCT-ND | RES_0805
55 | 1 | SW_DIP_220ADC16 | SWITCH ROTARY DIP HEX 100MA 50V | SW1 | CTS Electrocomponents | 220ADC16 | DigiKey | CT3070-ND | CTS_220ADC16
56 | 3 | SWITCH_EVQ-Q2U02W | SWITCH TACTILE SPST-NO 0.02A 15V | SW2, SW3, SW5 | Panasonic Electronic Components | EVQ-Q2U02W | Digi-Key | P12954SCT-ND | SW_EVQ-Q2U02W
57 | 1 | SWITCH_450302014072 | SWITCH MINI SLIDE RA 2.54mm | SW4 | Wurth Elektronik | 450302014072 | Mouser | 710-450302014072 | SWITCH_WURTH_450302014072
58 | 1 | IC_STM32F746NGH6U | STM32F746NGH6 (STM32F7 Birdie) TBGA216 | U1 | STMicroelectronics | STM32F746IGT6 | DigiKey | 497-15817-ND | QFP50P2600X2600X160-176N
59 | 1 | IC_ IS42S32400F-6TL | IC DRAM 128M PARALLEL 86TSOP II | U2 | ISSI, Integrated Silicon Solution Inc | IS42S32400F-6TL-TR | Mouser | 870-IS42S32400F-6TL | 86TSOPII
60 | 1 | IC_MT25QL128ABA1ESE-0SIT | IC FLASH 128M SPI 133MHZ 8SOP2 | U3 | Micron Technology Inc. | MT25QL128ABA1ESE-0SIT | Digi-Key | 557-1772-1-ND | SO8W
61 | 1 | IC_TPS61169DCKR | IC LED DRVR RGLTR DIM 1.8A SC70 | U4 | Texas Instruments | TPS61169DCKR | Digi-Key | 296-40821-1-ND | SC70-5_SOT-353_5-TSSOP
62 | 1 | IC_RCLAMP0504FATCT | TVS DIODE 5V 25V SC70-6 | U5 | Semtech Corporation | RCLAMP0504FATCT | Digi-Key | RCLAMP0504FATCTCT-ND | SOT-363_6-TSSOP_SC-88
63 | 1 | IC_STMPS2141MTR | IC PWR SWITCH N-CHANNEL 1:1 8SO | U6 | STMicroelectronics | STMPS2141MTR | Digi-Key | 497-6932-1-ND | SO-8
64 | 1 | IC_LIS3DHTR | ACCEL 2-16G I2C/SPI 16LGA | U7 | STMicroelectronics | LIS3DHTR | Digi-Key | 497-10613-1-ND | XDCR_LIS3DHTR
65 | 1 | MODULE_RCWL-1601 | MODULE ULTRASONIC SENSOR 3V | U8 | Adafruit Industries LLC | 4007 | Digi-Key | 1528-2832-ND | 4007
66 | 1 | IC_TPL0401A-10DCKR | IC DGTL POT 10KOHM 128TAP SC70-6 | U9 | Texas Instruments | TPL0401A-10DCKR | Digi-Key | 296-29676-1-ND | SOT-363_6-TSSOP_SC-88
67 | 1 | IC_OPAMP_TSV620ILT | IC OPAMP GP 1 CIRCUIT SOT23-6 | U10 | STMicroelectronics | TSV620ILT | Digi-Key | 497-10160-1-ND | SOT23-6
68 | 1 | IC_OPAMP_LM4861 | IC AMP CLASS AB MONO 1.5W 8SOIC | U11 | Texas Instruments | LM4861MX/NOPB | Digi-Key | 296-38566-1-ND | SO-8
69 | 1 | IC_NX3DV221TKX | IC USB 2.0 SWITCH HS 10HVSON | U12 | NXP USA Inc. | NX3DV221TKX | Digi-Key | 568-10368-1-ND | PMG_NX3DV221TKX
70 | 1 | MODULE_2491 | RX TXRX MOD WIFI TRACE ANT SMD 4MB | U13 | Adafruit Industries LLC | 2491 | Digi-Key | 1528-1438-ND | XCVR_ESP8266-12E/ESP-12E
71 | 1 | IC_MCP73826-4.1VCHTR | IC CONTROLLR LI-ION 4.1V SOT23-6 | U14 | Microchip Technology | MCP73826-4.1VCHTR | Digi-Key | MCP73826-4.1VCHCT-ND | SOT23-6
72 | 1 | IC_TPS63020DSJR | IC REG BCK BST ADJ 3.5A 14VSON | U15 | Texas Instruments | TPS63020DSJR | Digi-Key | 296-36491-1-ND | 14VSON
73 | 1 | IC_TPS61230DRCR | IC REG BOOST ADJ 4A 10VSON | U16 | Texas Instruments | TPS61230DRCR | Digi-Key | 296-37761-1-ND | 10VSON
74 | 1 | IC_LDS3985M33R | IC REG LINEAR 3.3V 300MA SOT23-5 | U17 | STMicroelectronics | LDS3985M33R | Digi-Key | 497-4257-1-ND | SOT23-5
75 | 1 | IC_COMPARATOR_MCP6546T-I/SN | IC COMP OPENDRN 1.6V SNGL 8-SOIC | U18 | Microchip Technology | MCP6546T-I/SN | Digi-Key | MCP6546T-I/SNCT-ND | SO-8
76 | 1 | IC_OSC_ECS-2520MVLC-250-BN-TR | XTAL OSC XO 25MHZ CMOS SMD | X1 | ECS Inc. | ECS-2520MVLC-250-BN-TR | Digi-Key | 50-ECS-2520MVLC-250-BN-CT-ND | OSC_ECS-2520S25-250-FN-TR
77 | 1 | XTAL_25HZ_6PF_SMD | CRYSTAL 25.0000MHZ 18PF SMD | X2 | ECS Inc. | ECS-250-18-7SX-TR | Digi-Key | XC2030-1-ND | XTAL_ECS
78 | 1 | XTAL_32.768KHZ_6PF_SMD | CRYSTAL 32.7680KHZ 6PF SMD | X3 | EPSON | MC-306 32.7680K-E0:PURE SN | Digi-Key | SER4097CT-ND | XTAL_ECS-.327-6-17X-TR
Approved |  |  |  |  | Notes |  |  | Total Items in BOM | 242

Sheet: Project Information
Project Full Path | C:\IMR_Projects\HabProjects\TechDemo\Hardware\TechDemo.PrjPcb
Project Filename | TechDemo.PrjPcb
Variant Name | None
Data-Source Filename | TechDemo.PrjPcb
Data-Source Full Path | C:\IMR_Projects\HabProjects\TechDemo\Hardware\TechDemo.PrjPcb
Title | Bill of Materials for Project [TechDemo.PrjPcb] (No PCB Document Selected)
Total Quantity | 242
Report Time | 9:34 AM
Report Date | 4/16/2021
Report Date & Tine | 4/16/2021 9:34 AM
Output Name | Bill of Materials
Output Type | BOM_PartType
Output Generator Name | BOM
Output Generator Description | Bill of Materials
Total Actual Price | <Parameter TotalActualPrice not found>
Total Target Price | <Parameter TotalTargetPrice not found>

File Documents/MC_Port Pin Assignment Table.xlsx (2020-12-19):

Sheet: LQFP 144
TECHNOLOGY DEMONSTRATOR
STM32F746ZG LQFP 144
SIGNAL NAME | PORT | LQFP 144
LCD TFT DIPLAY |  |  |  |  |  |  | CONFLICTING PORT PINS |  |  |  |  | USE HIGHER PIN COUNT CHIP
LCD_R0 | PG13 | 128 |  |  |  |  | PORT PIN | USE1 | USE2 | COMMENT |  | RISK | Pin Count 176 vs 144 | -3
LCD_R1 | PA2 | 36 |  |  |  |  | PA1 | LCD | QUAD SPI | Use LCD |  |  | More Expensive | -2
LCD_R2 | PA1 | 35 | ~~PC10~~ | 111 |  |  | PC0 | LCD | SDRAM | Use LCD |  |  | Harder to solder | -5
LCD_R3 | PB0 | 46 |  |  |  |  | PE15 | LCD | SDRAM | USE SDRAM: NO OTHER OPTION | L |  | More PCB Space | -2
LCD_R4 | PA5 | 41 | ~~PA11~~ | 103 |  |  | PE11 | LCD | SDRAM | USE SDRAM: NO OTHER OPTION | L | MITIGATE - | More expensive | -6
LCD_R5 | PC0 | 26 | ~~PA12~~ | 104 |  |  | PG12 | LCD | LCD | UNRESOLVE | L | MITIGATE + | Have Bittle Build | 7
LCD_R6 | PB1 | 47 | ~~PA8~~ | 100 |  |  | PD10 | LCD | SDRAM | USE SDRAM: NO OTHER OPTION | L | REWARD | Can support fully support RGB888 | 7
LCD_R7 | ~~PE15~~ | 68 | PG6 | 91 |  |  | PE12 | LCD | SDRAM | USE SDRAM: NO OTHER OPTION | L |  | More pins for Expansion Module | 5
LCD_G0 | PE5 | 4 |  |  |  |  | PE14 | LCD | SDRAM | USE SDRAM: NO OTHER OPTION | L |  | More design options | 5
LCD_G1 | PE6 | 5 |  |  |  |  | PC9 | uSD Card | QUAD SPI | USE: uSD Card: NO OTHER OPTION | L |  | Mimics more closely reference design | 7
LCD_G2 | PA6 | 42 |  |  |  |  | PC10 | LCD | uSD Card | USE: uSD Card: NO OTHER OPTION | L
LCD_G3 | ~~PE11~~ | 64 | PG10 | 125 |  |  | PA11 | LCD | USB OTG | USE USB OTG: NO OTHER OPTION
LCD_G4 | PB10 | 69 |  |  |  |  | PA12 | LCD | USB OTG | USE USB OTG: NO OTHER OPTION
LCD_G5 | PB11 | 70 |  |  |  |  | PA8 | LCD | USB OTG | USE USB OTG: NO OTHER OPTION
LCD_G6 | PC7 | 97
LCD_G7 | PD3 | 117 |  |  |  |  |  |  |  |  |  |  |  | 13
LCD_B0 | PE4 | 3
LCD_B1 | PG12 | 127
LCD_B2 | PD6 | 122 | PG10 | 125
LCD_B3 | ~~PD10~~ | 79 | PG11 | 126
LCD_B4 | ~~PE12~~ | 65 | PG12 | 127
LCD_B5 | PA3 | 37
LCD_B6 | PB8 | 139
LCD_B7 | PB9 | 140
LCD_CLK | ~~PE14~~ | 67 | PG7 | 92
LCD_DE | PF10 | 22 | PE13 | 66
LCD_VSYNC | PA4 | 40
LCD_HSYNC | PC6 | 96
BL_PWM
uSD CARD
SDMMC1_D0 | PC8 | 98
SDMMC1_D1 | PC9 | 99
SDMMC1_D2 | PC10 | 111
SDMMC1_D3 | PC11 | 112
SDMMC1_CLK | PC12 | 113
SDMMC1_CMD | PD2 | 116
SD_DETECT |  |  |  |  | SUGGEST PC13
QUAD SPI FLASH
QUADSPI_CLK | PB2 | 48
QUADSPI_BK1_NCS | PB6 | 136
QUADSPI_BKI_IO0 | PF8 | 20 | PD11 | 80 | ~~PC9~~ | 99
QUADSPI_BK1_IO1 | PF9 | 21 | PD12 | 81 | ~~PC10~~ | 111
QUADSPI_BK1_IO2 | PE2 | 1 | PF7 | 19
QUADSPI_BK1_IO3 | PF6 | 18 | ~~PA1~~ | 35 | PD13 | 82
SDRAM 1
FMC_A0 | PF0 | 10
FMC_A1 | PF1 | 11
FMC_A2 | PF2 | 12
FMC_A3 | PF3 | 13
FMC_A4 | PF4 | 14
FMC_A5 | PF5 | 15
FMC_A6 | PF12 | 50
FMC_A7 | PF13 | 53
FMC_A8 | PF14 | 54
FMC_A9 | PF15 | 55
FMC_A10 | PG0 | 56
FMC_A11 | PG1 | 57
FMC_BA0 | PG4 | 89
FMC_BA1 | PG5 | 90
FMC_D0 | PD14 | 85
FMC_D1 | PD15 | 86
FMC_D2 | PD0 | 114
FMC_D3 | PD1 | 115
FMC_D4 | PE7 | 58
FMC_D5 | PE8 | 59
FMC_D6 | PE9 | 60
FMC_D7 | PE10 | 63
FMC_D8 | PE11 | 64
FMC_D9 | PE12 | 65
FMC_D10 | PE13 | 66
FMC_D11 | PE14 | 67
FMC_D12 | PE15 | 68
FMC_D13 | PD8 | 77
FMC_D14 | PD9 | 78
FMC_D15 | PD10 | 79
FMC_NBL0 | PE0 | 141
FMC_NBL1 | PE1 | 142
FMC_SDCKE0 | PC3 | 29
FMC_SDCLK | PG8 | 93
FMC_SDNCAS | PG15 | 132
FMC_SDNE0 | PC2 | 28 | PC4 | 44
FMC_SDNRAS | PF11 | 49
FMC_SDNWE | ~~PC0~~ | 26 | PA7 | 43
USB OTG FS
OTG_FS_VBUS | PA9 | 101 |  |  | NOT USED FOR DEVICE PUT ANYWHERE (This has to do with sensing the presence (input) of VBUS)
OTG_FS_DM | PA11 | 103
OTG_FS_DP | PA12 | 104
OTG_FS_ID | PA10 | 102
OTG_FS_SOF | PA8 | 100 |  |  | NOT USED FOR DEVICE PUT ANYWHERE (Start Of Frame)
OTG_FS_PwrSwitch |  |  |  |  | NOT USED FOR DEVICE PUT ANYWHERE

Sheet: LQFP 176
TECHNOLOGY DEMONSTRATOR
STM32F746IGT LQFP 176
SIGNAL NAME | PORT | LQFP 176
LCD TFT DIPLAY
LTDC_B0 | PE4 | 3 | PG14 | 157
LTDC_B1 | PG12 | 155
LTDC_B2 | PD6 | 150 | PG10 | 153
LTDC_B3 | PG11 | 154 | PG11 | 154 | PD10 | 98 | PD10 | 98
LTDC_B4 | PI4 | 173 | PG12 | 155 | PI4 | 173 | PE12 | 75
LTDC_B5 | P15 | 174 |  |  | PI5 | 174 | PA3 | 47
LTDC_B6 | PI6 | 175 |  |  | PI6 | 175 | PB8 | 167
LTDC_B7 | PB9 | 168 |  |  | PI7 | 176
LTDC_CLK | PG7 | 111 | PG7 | 111 |  |  | PE14 | 77
LTDC_DE | PF10 | 28 | PE13 | 76
LTDC_G0 | PE5 | 4
LTDC_G1 | PE6 | 5
LTDC_G2 | PH13 | 128 |  |  | PH13 | 128 | PA6 | 52
LTDC_G3 | PH14 | 129 | PG10 | 153 | PH14 | 129 | PE11 | 74
LTDC_G4 | PH15 | 130 |  |  | PH15 | 130 | PB10 | 79
LTDC_G5 | PI0 | 131 | P10 | 131 |  |  | PB11 | 80
LTDC_G6 | PC7 | 116 |  |  | PI1 | 132
LTDC_G7 | PI2 | 133 |  |  | PI2 | 133 | PD3 | 145
LTDC_HSYNC | PI10 | 12 |  |  | PI10 | 12 | PC6 | 115
LTDC_R0 | PH2 | 43 | PH2 | 43 |  |  | PG13 | 156
LTDC_R1 | PH3 | 44 | PH3 | 44 |  |  | PA2 | 42
LTDC_R2 | PA1 | 41 | PC10 | 139 | PH8 | 85
LTDC_R3 | PB0 | 56 |  |  | PH9 | 86
LTDC_R4 | PH10 | 87 | PA11 | 122 | PH10 | 87 | PA5 | 51
LTDC_R5 | PH11 | 88 | PA12 | 123 | PH11 | 88 | PC0 | 32
LTDC_R6 | PB1 | 57 | PA8 | 119 | PH12 | 89
LTDC_R7 | PG6 | 110 | PG6 | 110 |  |  | PE15 | 78
LTDC_VSYNC | PI9 | 11 |  |  | PI9 | 11 | PA4 | 50
DISPLAY_EN | PI1
PWM_DISPLAY | PA15
LCD TOUCH (I2C3)
LCD_SCL | PH7 | 84 | PA8 | 119
LCD_SDA | PH8 | 85 | PC9 | 118
TOUCH_IRQ | PH6 |  |  |  |  |  | SET AS AN IRQ
TOUCH_NRST | PH9 |  |  |  |  |  | SET AS A RESET
uSD CARD
SDMMC1_D0 | PC8 | 117
SDMMC1_D1 | PC9 | 118
SDMMC1_D2 | PC10 | 139
SDMMC1_D3 | PC11 | 140
SDMMC1_CLK | PC12 | 141
SDMMC1_CMD | PD2 | 144
USD_DET | PC13 |  |  |  | SUGGEST PC13 |  | I think this can change
QUAD SPI FLASH
QUADSPI_CLK | PB2 | 58
QUADSPI_BK1_NCS | PB6 | 164
QUADSPI_BKI_IO0 | PF8 | 26 | PD11 | 99 | PC9 | 118
QUADSPI_BK1_IO1 | PF9 | 27 | PD12 | 100 | PC10 | 139
QUADSPI_BK1_IO2 | PF7 | 25 | PE2 | 1
QUADSPI_BK1_IO3 | PF6 | 24 | PA1 | 41 | PD13 | 101
SDRAM 1
FMC_A0 | PF0 | 16
FMC_A1 | PF1 | 17
FMC_A2 | PF2 | 18
FMC_A3 | PF3 | 19
FMC_A4 | PF4 | 20
FMC_A5 | PF5 | 21
FMC_A6 | PF12 | 60
FMC_A7 | PF13 | 63
FMC_A8 | PF14 | 64
FMC_A9 | PF15 | 65
FMC_A10 | PG0 | 66
FMC_A11 | PG1 | 67
FMC_BA0 | PG4 | 108
FMC_BA1 | PG5 | 109
FMC_D0 | PD14 | 104
FMC_D1 | PD15 | 105
FMC_D2 | PD0 | 142
FMC_D3 | PD1 | 143
FMC_D4 | PE7 | 68
FMC_D5 | PE8 | 69
FMC_D6 | PE9 | 70
FMC_D7 | PE10 | 73
FMC_D8 | PE11 | 74
FMC_D9 | PE12 | 75
FMC_D10 | PE13 | 76
FMC_D11 | PE14 | 77
FMC_D12 | PE15 | 78
FMC_D13 | PD8 | 96
FMC_D14 | PD9 | 97
FMC_D15 | PD10 | 98
FMC_NBL0 | PE0 | 169
FMC_NBL1 | PE1 | 170
FMC_SDCKE0 | PC3 | 35 | PH2 | 43 | PC5 | 55
FMC_SDCLK | PG8 | 112
FMC_SDNCAS | PG15 | 160
FMC_SDNE0 | PC4 | 54 | PH3 | 44 | PC4 | 34
FMC_SDNRAS | PF11 | 59
FMC_SDNWE | PC0 | 32 | PH5 | 46 | PA7 | 53
USB OTG FS
OTG_FS_VBUS | PA9 | 120 |  |  | NOT USED FOR DEVICE PUT ANYWHERE (This has to do with sensing the presence (input) of VBUS)
OTG_FS_VBUS_NEN | PA8
OTG_FS_VBUS_NER | PI3
OTG_FS_N | PA11 | 122
OTG_FS_P | PA12 | 123
OTG_FS_ID | PA10 | 121 |  |  | NOT USED FOR DEVICE PUT ANYWHERE (Start Of Frame)
OTG_FS_SOF |  | 119 |  |  | NOT USED FOR DEVICE PUT ANYWHERE (Start Of Frame)
OTG_FS_PwrSwitch |  |  |  |  | NOT USED FOR DEVICE PUT ANYWHERE
USART3: DEBUG PORT
USART3_TX | PB10
USART3_RX | PB11
ADC
ADC1_IN5 (UI) | PA5
ADC1_IN6 (VBAT) | PA6
PWM (TIMER)
PWM_RLED | PD13
PWM_GLED | PD12
SPI1: ACCELEROMETER
SPI1_CLK | PB3
SPI1_MISO | PB4
SPI1_MOSI | PB5
ACEL_NEN | PG9
SPI2: EXPANSION
SPI2_CLK | PB13
SPI2_MISO | PC1
SPI2_MOSI | PC2
GPIO: EXPANSION MOD
MOD_IO0 | PB12
MOD_IO1 | PB14
TYPE_ID0 | PB15
TYPE_ID1 | PD11
AUDIO POT: I2C1
I2C1_SCL | PB8
I2C1_SDA | PB7
AUDIO: GPIO
AUDIO_EN | PI7
AUDIO:DAC
DAC_OUT1 | PA4
UI_HEX: GPIO
HEX_1 | PD7
HEX_2 | PD4
HEX_4 | PD5
HEX_8 | PD3
UI_ULTRASONIC_GPIO
US_TRIG | PE2
US_ECHO | PE3
WIFI: USART2
USART2_TX | PA2
USART2_RX | PA3
WIFI: GPIO
WIFI_EN | PA0
POWER: GPIO
5V_EN
5V_GOOD
STATUS_LED | PG2

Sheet: Sheet1
LTDC_R0 | PG13 | 156 | PH2 | 43
LTDC_R1 | PA2 | 42 | PH3 | 44
LTDC_R2 | PA1 | 41 | PC10 | 139 | PH8 | 85
LTDC_R3 | PB0 | 56 |  |  | PH9 | 86
LTDC_R4 | PA5 | 51 | PA11 | 122 | PH10 | 87
LTDC_R5 | PC0 | 32 | PA12 | 123 | PH11 | 88
LTDC_R6 | PB1 | 57 | PA8 | 119 | PH12 | 89
LTDC_R7 | PE15 | 78 | PG6 | 110
LTDC_G0 | PE5 | 4
LTDC_G1 | PE6 | 5
LTDC_G2 | PA6 | 52 |  |  | PH13 | 128
LTDC_G3 | PE11 | 74 | PG10 | 153 | PH14 | 129
LTDC_G4 | PB10 | 79 |  |  | PH15 | 130
LTDC_G5 | PB11 | 80 | P10 | 131
LTDC_G6 | PC7 | 116 |  |  | PI1 | 132
LTDC_G7 | PD3 | 145 |  |  | PI2 | 133
LTDC_B0 | PE4 | 3 | PG14 | 157
LTDC_B1 | PG12 | 155
LTDC_B2 | PD6 | 150 | PG10 | 153
LTDC_B3 | PD10 | 98 | PG11 | 154
LTDC_B4 | PE12 | 75 | PG12 | 155 | PI4 | 173
LTDC_B5 | PA3 | 47 |  |  | PI5 | 174
LTDC_B6 | PB8 | 167 |  |  | PI6 | 175
LTDC_B7 | PB9 | 168 |  |  | PI7 | 176
LTDC_CLK | PE14 | 77 | PG7 | 111
LTDC_DE | PF10 | 28 | PE13 | 76
LTDC_VSYNC | PA4 | 50 |  |  | PI9 | 11
LTDC_HSYNC | PC6 | 115 |  |  | PI10 | 12

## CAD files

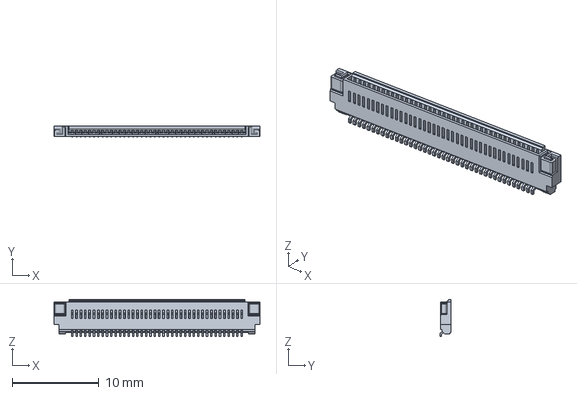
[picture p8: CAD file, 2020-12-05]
Hardware/3D_Models/CONN_MOLEX_512964033.stp
23.7 x 1.30 x 4.30 mm

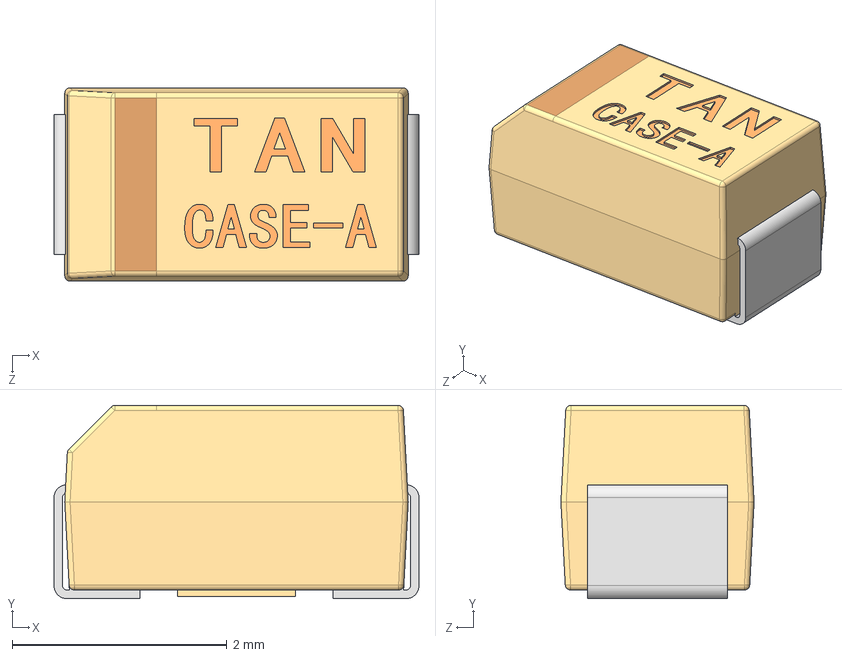
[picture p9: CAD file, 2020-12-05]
Hardware/3D_Models/CAP_TANT_C3216_1206.step
3.40 x 1.80 x 1.80 mm

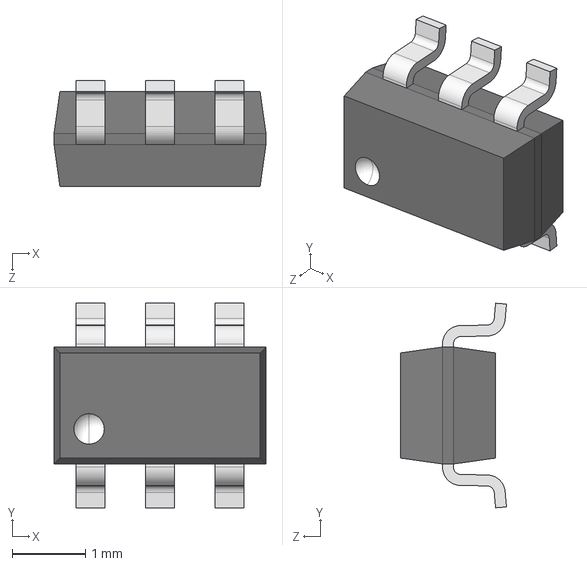
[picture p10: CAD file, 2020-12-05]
Hardware/3D_Models/SOT23-6.step
2.90 x 2.80 x 1.45 mm

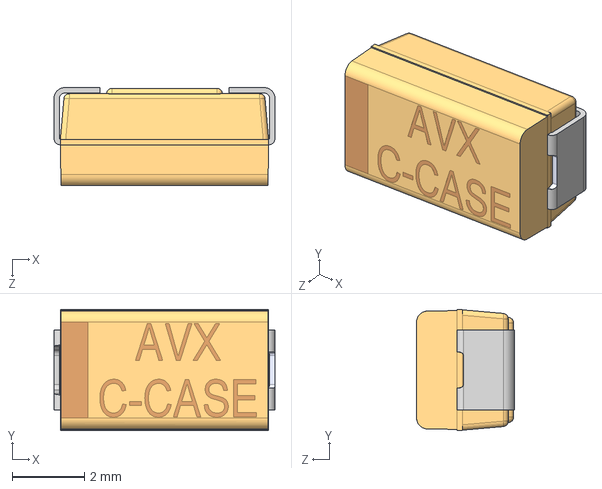
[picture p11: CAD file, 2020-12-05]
Hardware/3D_Models/CAP_2312.step
6.10 x 3.35 x 2.70 mm

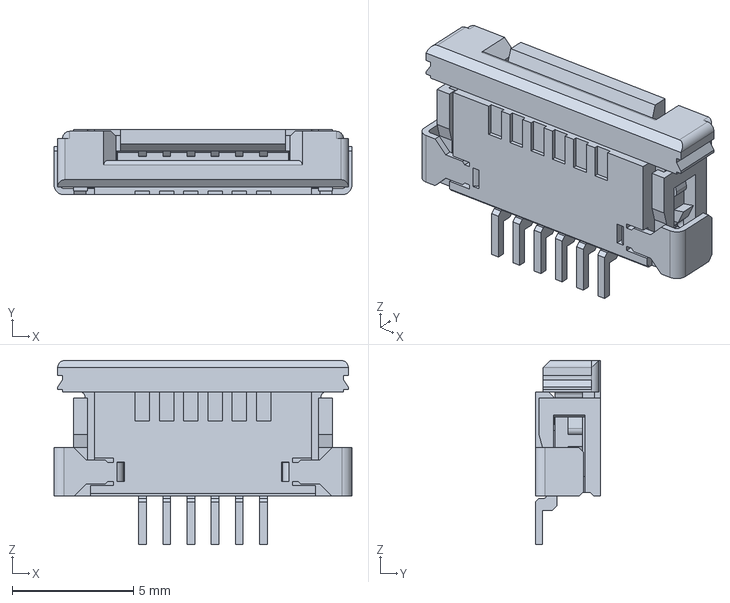
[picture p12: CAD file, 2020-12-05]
Hardware/3D_Models/CONN_MOLEX_522070660.stp
12.3 x 2.70 x 7.60 mm

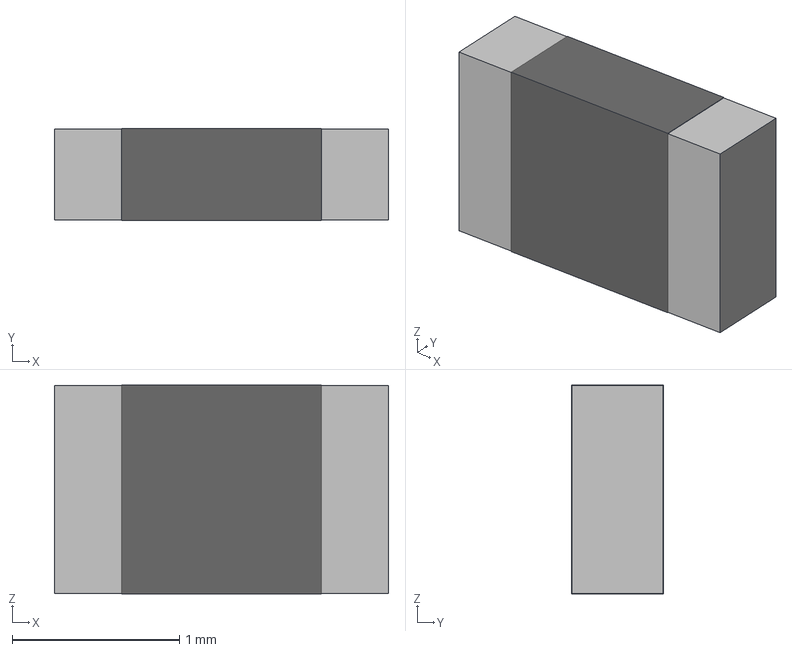
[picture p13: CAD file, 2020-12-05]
Hardware/3D_Models/RES_0805_LOOK2.stp
2.00 x 0.55 x 1.25 mm

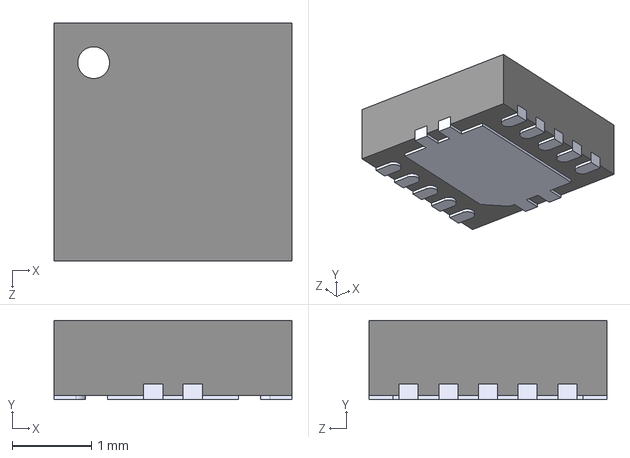
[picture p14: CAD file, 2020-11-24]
Hardware/3D_Models/10VSON.STEP
3.00 x 1.00 x 3.00 mm

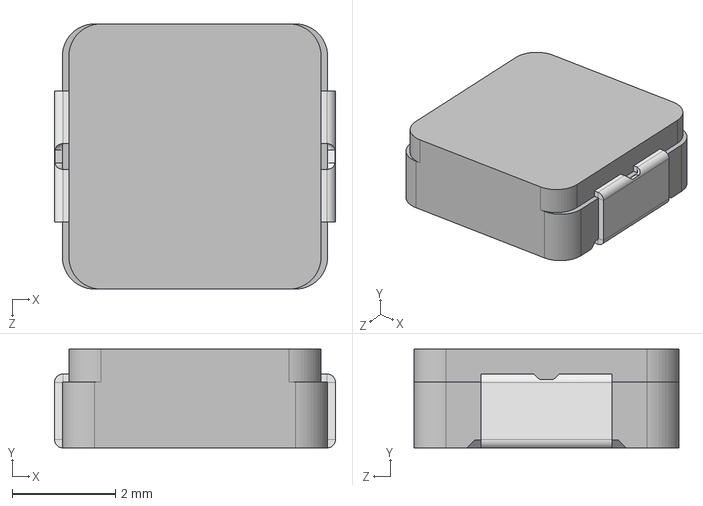
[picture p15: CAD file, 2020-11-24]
Hardware/3D_Models/VISHAY_IHLP-2020BZ-01.stp
5.45 x 1.92 x 5.15 mm

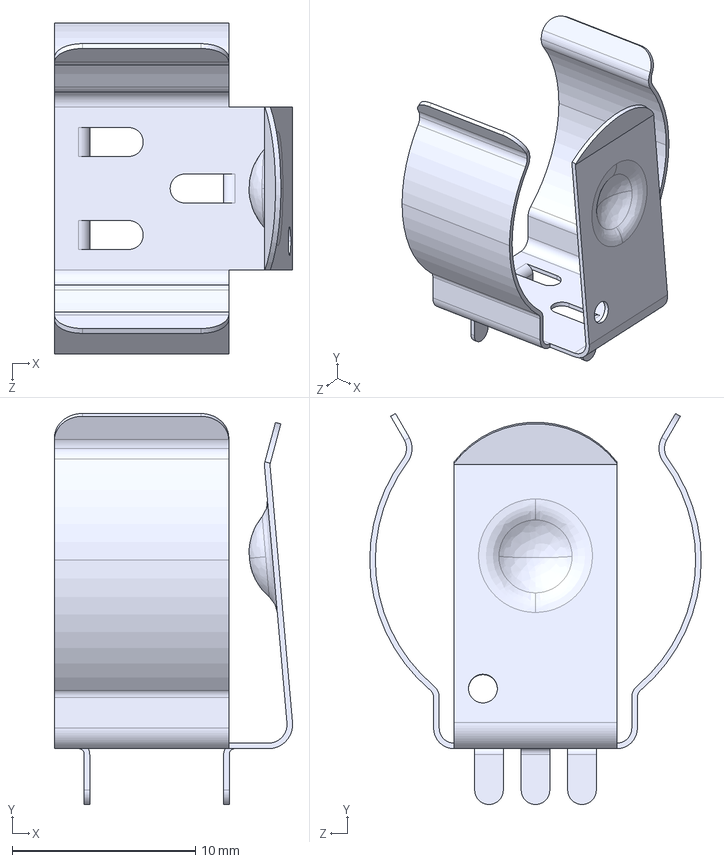
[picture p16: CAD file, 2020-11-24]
Hardware/3D_Models/KEYSTONE_54.step
13.0 x 21.4 x 18.1 mm

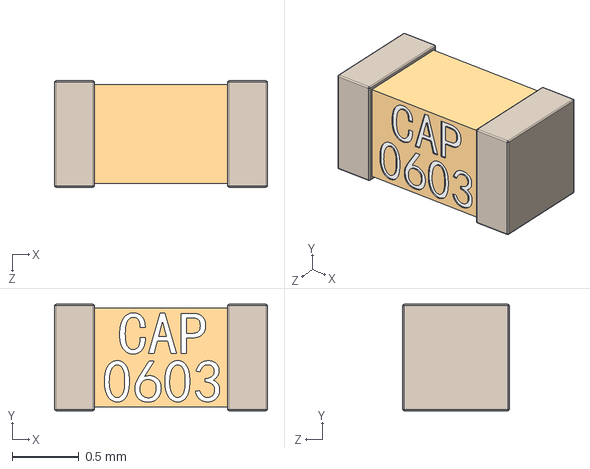
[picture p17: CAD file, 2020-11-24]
Hardware/3D_Models/CAP_0603.STEP
1.60 x 0.8 x 0.8 mm

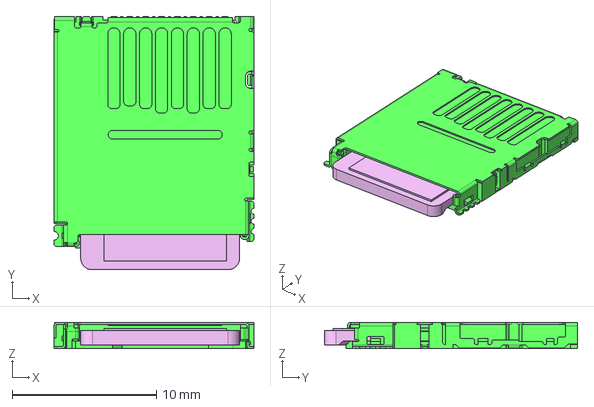
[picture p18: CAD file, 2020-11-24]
Hardware/3D_Models/DM3BT-DSF-PEJS.stp
13.8 x 17.6 x 1.83 mm
CARD
DM3BT

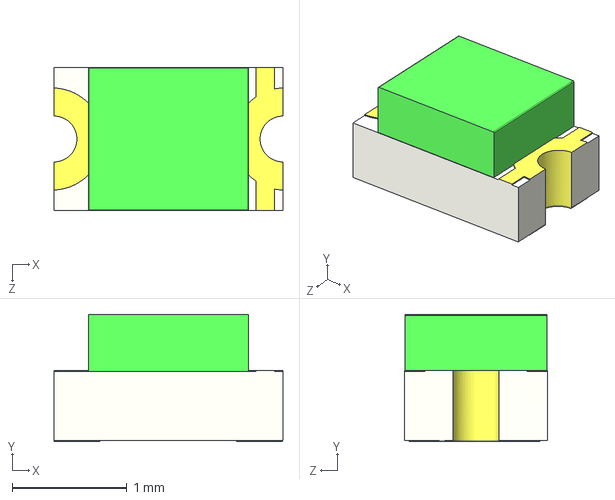
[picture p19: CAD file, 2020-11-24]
Hardware/3D_Models/LED_GREEN_0805.step
2.00 x 1.11 x 1.25 mm

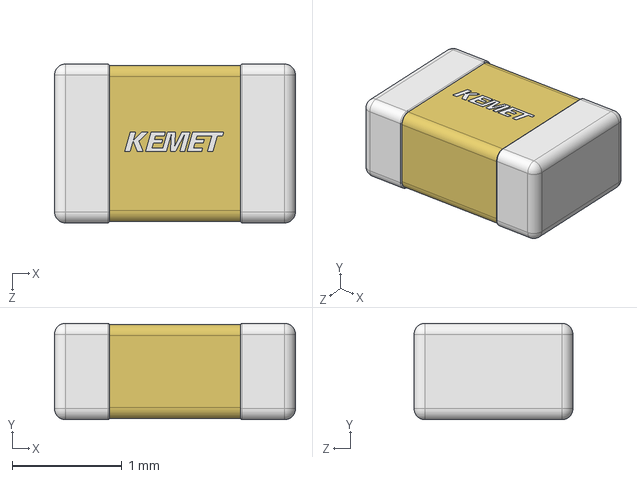
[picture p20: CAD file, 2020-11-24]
Hardware/3D_Models/CAP_0805.stp
2.20 x 0.88 x 1.45 mm
Base_26
Termination_26 x 2

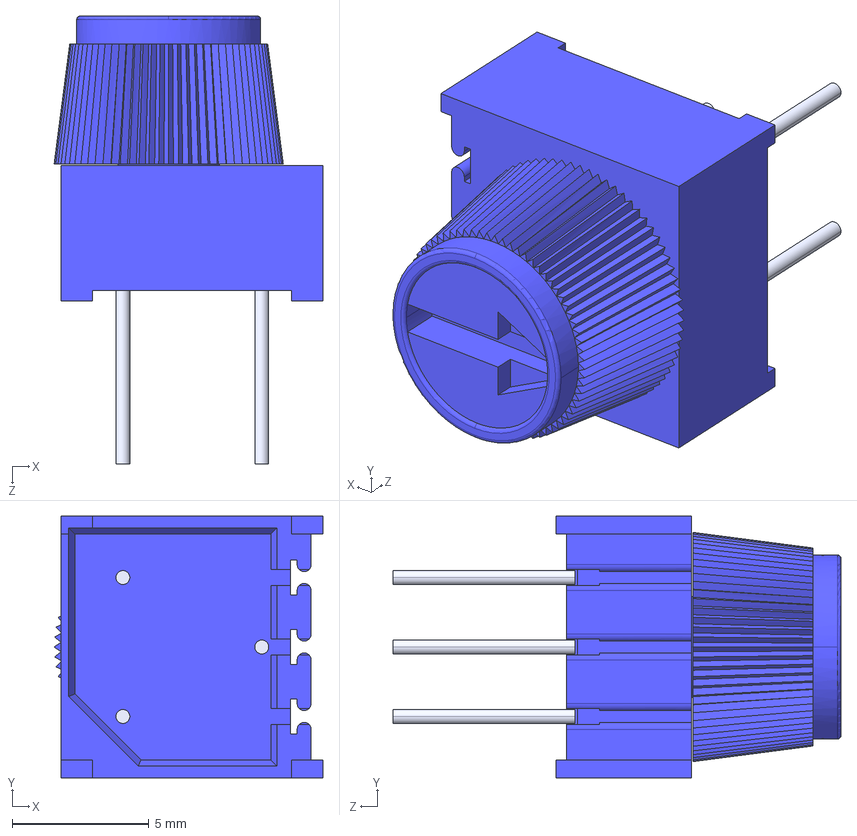
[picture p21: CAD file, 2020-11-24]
Hardware/3D_Models/BOURNS_3386F.STEP
9.83 x 9.58 x 16.4 mm
MANIFOLD_SOLID_BREP_18751
MANIFOLD_SOLID_BREP_18840
MANIFOLD_SOLID_BREP_18929
MANIFOLD_SOLID_BREP_19018

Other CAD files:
Hardware/3D_Models/RES_0805.step
Hardware/3D_Models/SOT-23.STEP
Hardware/3D_Models/COILCRAFT_LPS4018.step
Hardware/3D_Models/1206.step
Hardware/3D_Models/14VSON.step
Hardware/3D_Models/47589-0001.stp
Hardware/3D_Models/4PLCC-LED.step
Hardware/3D_Models/CAP_ALE_SMD_6.6x6.6.STEP
Hardware/3D_Models/CONN_HDR_1X2_100MIL.stp
Hardware/3D_Models/CONN_HDR_1X3_100MIL.stp
Hardware/3D_Models/CONN_HDR_1X6_100MIL.stp
Hardware/3D_Models/CONN_HDR_SOCKET_1X5_100MIL.step
Hardware/3D_Models/CONN_MOLEX_522710679.stp
Hardware/3D_Models/CONN_MOLEX_541044033.stp
Hardware/3D_Models/ECS-250-18-7SX-TR.STEP
Hardware/3D_Models/ECX-32.STEP
Hardware/3D_Models/IND_SDR0403.step
Hardware/3D_Models/RES_0603.STEP
Hardware/3D_Models/SC70-5_SOT-353_5-TSSOP.STEP
Hardware/3D_Models/SMB.step
Hardware/3D_Models/SOD123.STEP
Hardware/3D_Models/SOD323.STEP
Hardware/3D_Models/SOIC8.step
Hardware/3D_Models/SOIC8_WIDE.step
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

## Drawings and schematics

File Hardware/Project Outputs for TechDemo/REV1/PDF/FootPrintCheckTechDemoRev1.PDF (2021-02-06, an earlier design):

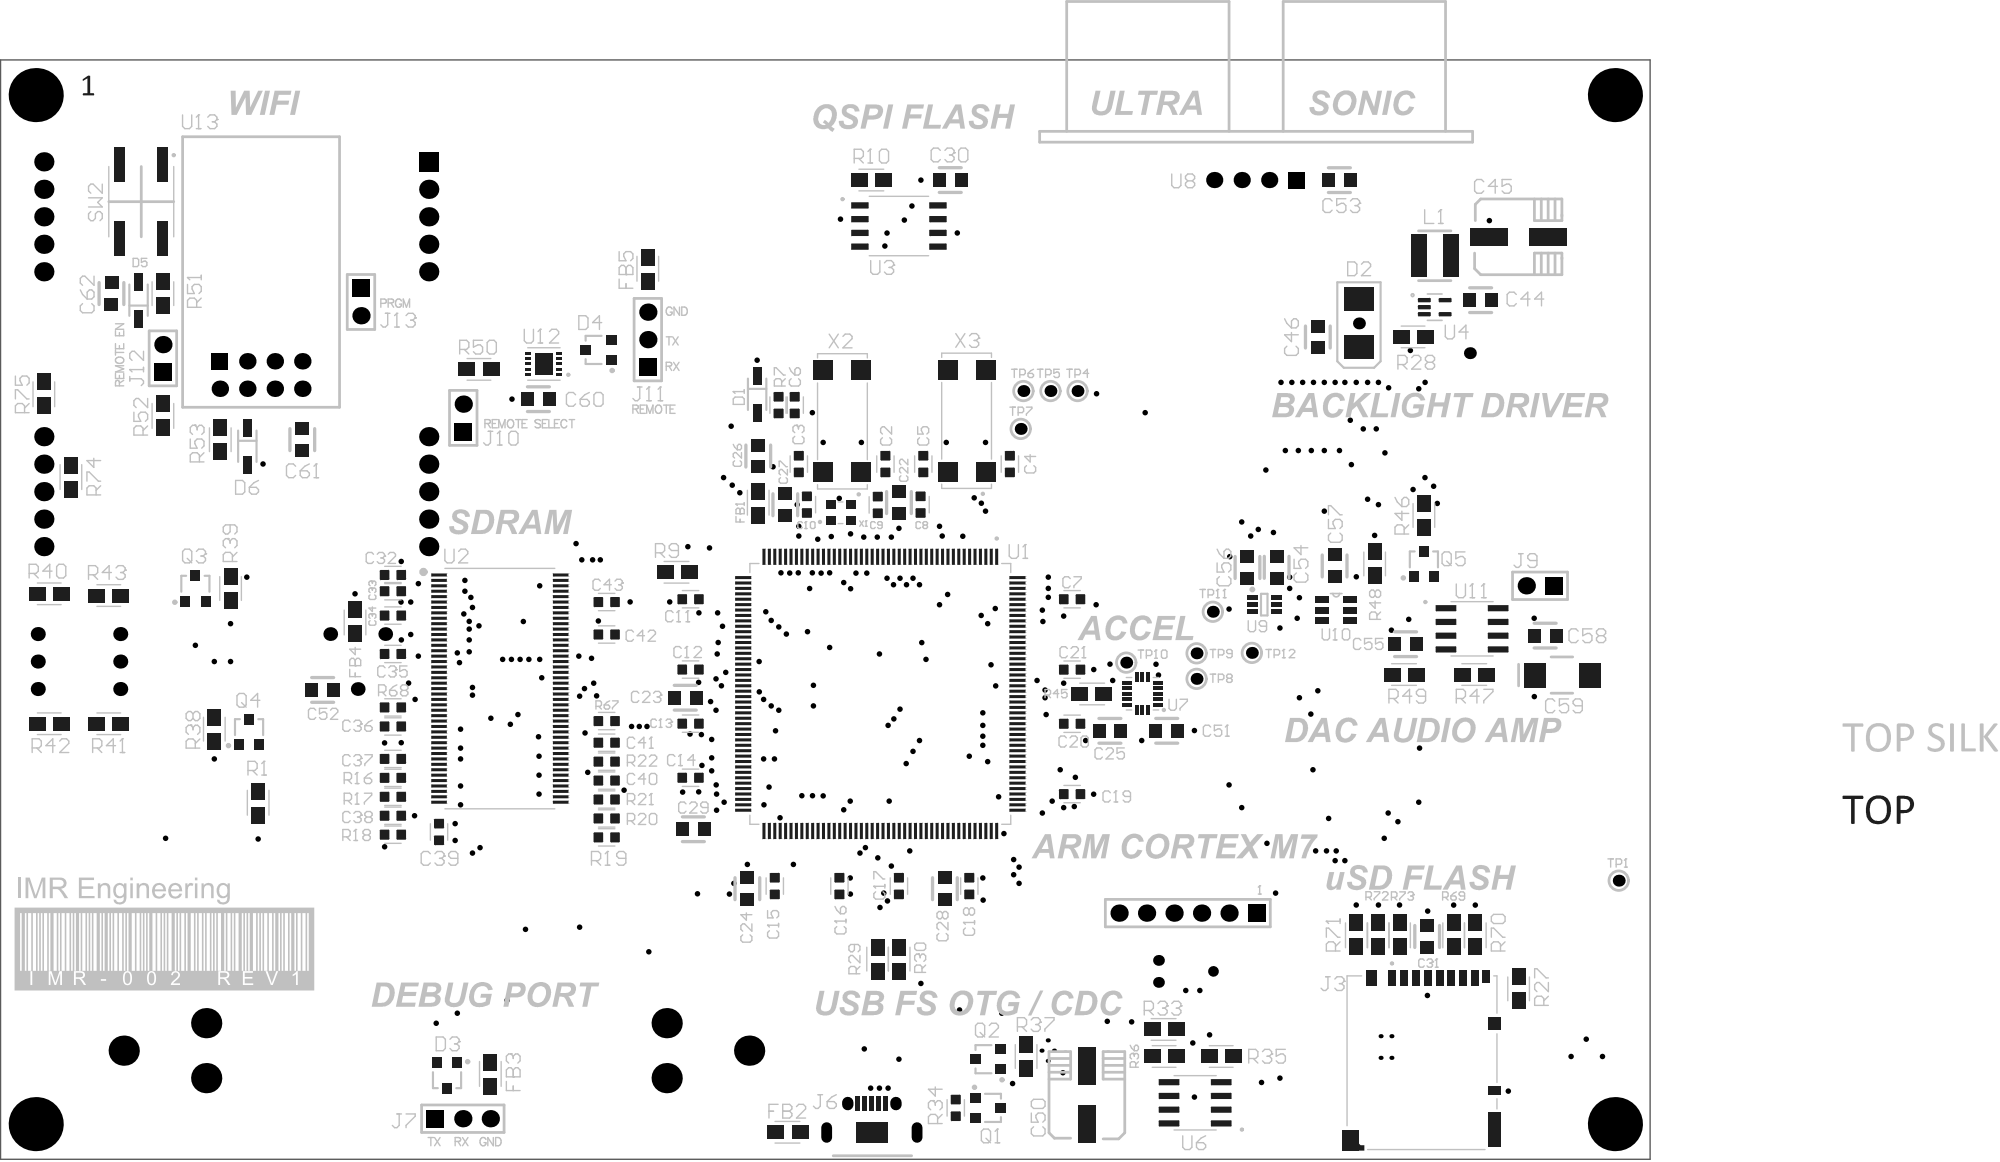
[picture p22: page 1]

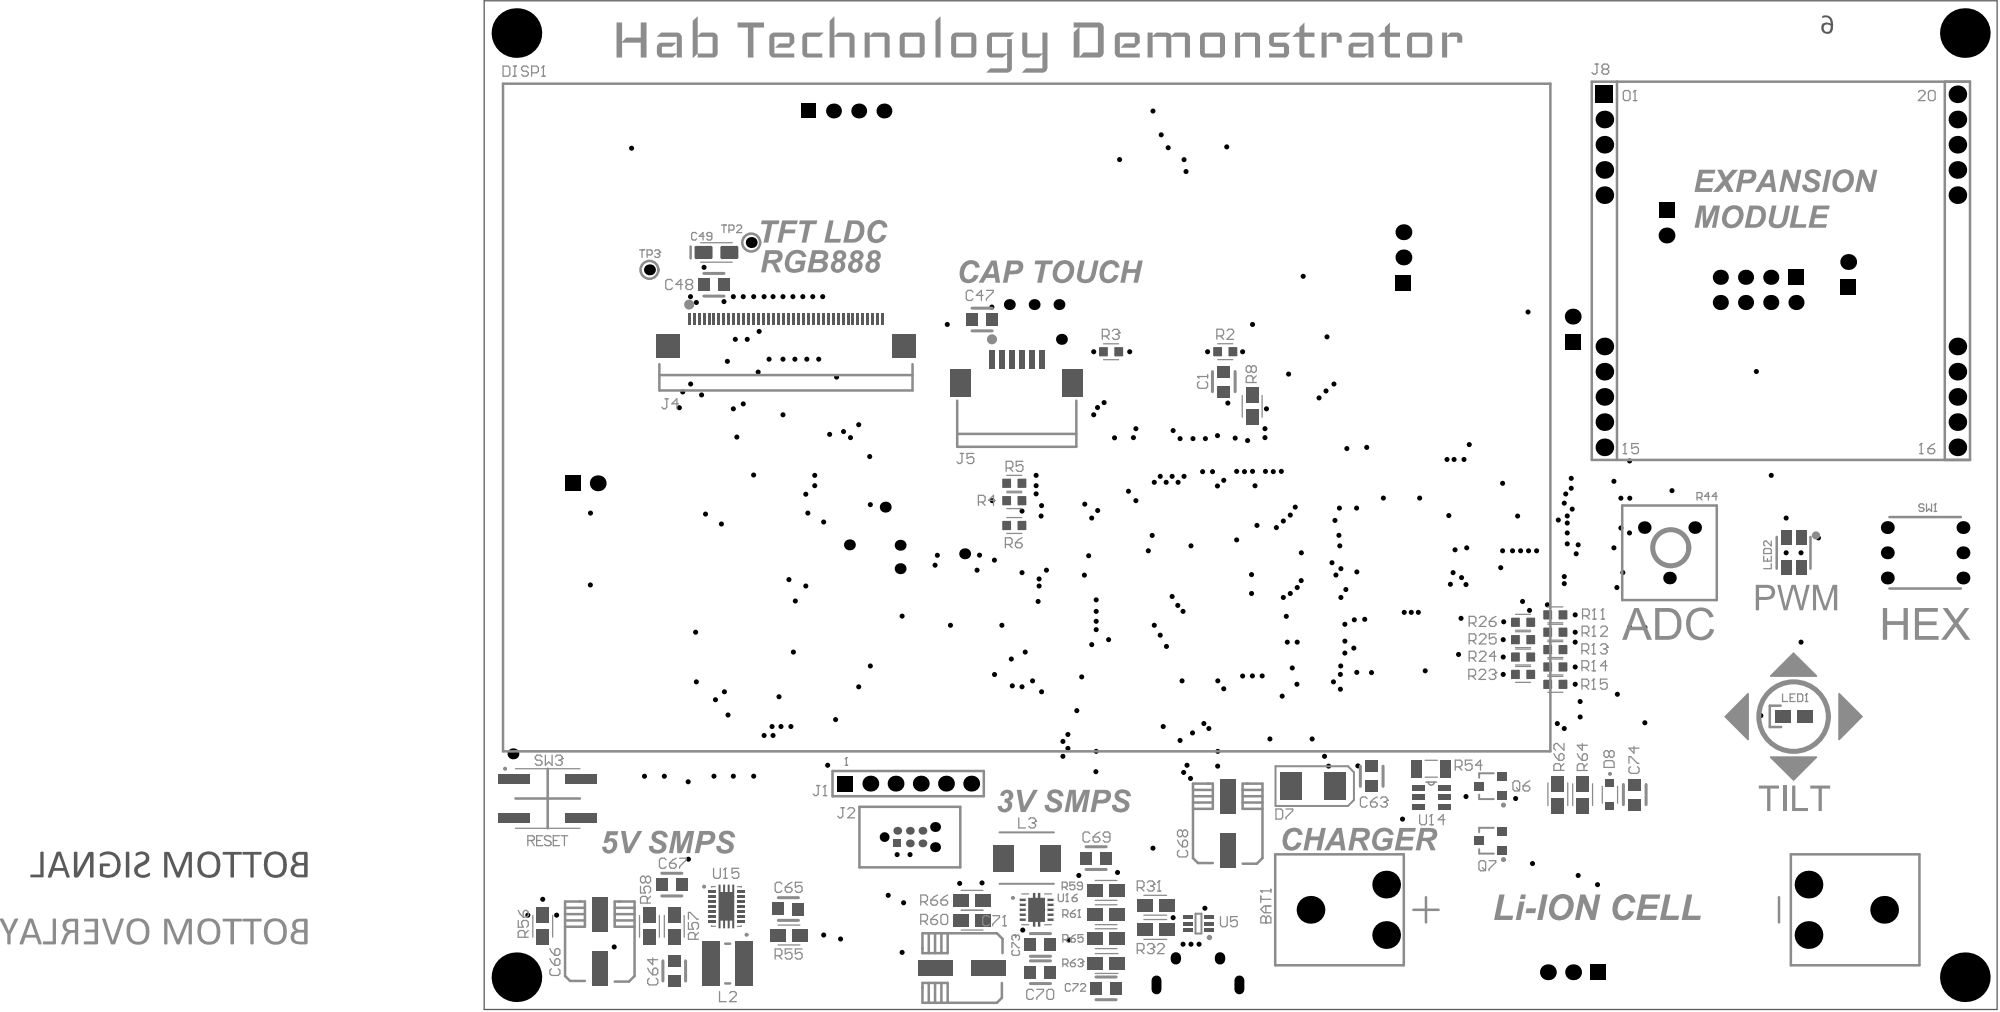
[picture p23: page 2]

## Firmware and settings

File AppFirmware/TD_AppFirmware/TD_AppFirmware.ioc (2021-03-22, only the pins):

PD12.GPIO_Label=PWM_GLED
PG4.Signal=FMC_A14_BA0
PG8.Signal=FMC_SDCLK
PH6.GPIO_Label=TOUCH_IRQ
PG0.Signal=FMC_A10
PG13.Signal=GPIO_Output
PH9.Signal=GPIO_Output
PD4.Signal=GPIO_Input
PB6.Signal=QUADSPI_BK1_NCS
PC7.Signal=LTDC_G6
PH1/OSC_OUT.Signal=RCC_OSC_OUT
PC3.Signal=FMC_SDCKE0
PD0.Signal=FMC_D2_DA2
PD8.Signal=FMC_D13_DA13
PE5.Signal=LTDC_G0
PE1.Signal=FMC_NBL1
PB2.Signal=QUADSPI_CLK
PE9.Signal=FMC_D6_DA6
PI6.Signal=LTDC_B6
PE2.Signal=QUADSPI_BK1_IO2
PA8.Signal=GPIO_Output
PF3.Signal=FMC_A3
PE10.Signal=FMC_D7_DA7
PB9.Signal=LTDC_B7
PB1.Signal=LTDC_R6
PD12.Signal=S_TIM4_CH1
PH2.Signal=LTDC_R0
PF14.Signal=FMC_A8
PD15.Signal=FMC_D1_DA1
PG12.Signal=LTDC_B1
PH15.Signal=LTDC_G4
PH13.Signal=LTDC_G2
PG5.Signal=FMC_A15_BA1
PG9.Signal=GPIO_Output
PD3.Signal=GPIO_Input
PD7.Signal=GPIO_Input
PD1.Signal=FMC_D3_DA3
PC0.Signal=FMC_SDNWE
PG13.GPIO_Label=PWR_5V_EN
PD10.Signal=FMC_D15_DA15
PA8.GPIO_Label=OTG_FS_VUSB_NEN
PB10.Signal=USART3_TX
PA5.Signal=ADCx_IN5
PH9.GPIO_Label=TOUCH_NRST
PI7.Signal=GPIO_Output
PE14.Signal=FMC_D11_DA11
PE15.Signal=FMC_D12_DA12
PE8.Signal=FMC_D5_DA5
PI1.Signal=GPIO_Output
PI2.Signal=LTDC_G7
PA0/WKUP.GPIO_Label=WIFI_EN
PF13.Signal=FMC_A7
PB5.Signal=SPI1_MOSI
PH6.Signal=GPIO_Input
PF9.Signal=QUADSPI_BK1_IO1
PC15/OSC32_OUT.Signal=RCC_OSC32_OUT
PF4.Signal=FMC_A4
PB0.Signal=LTDC_R3
PI1.GPIO_Label=DISPLAY_EN
PG6.Signal=LTDC_R7
Mcu.UserName=STM32F746IGTx
PH14.Signal=LTDC_G3
PH10.Signal=LTDC_R4
PG2.Signal=GPIO_Output
PA0/WKUP.Signal=GPIO_Output
PB11.Signal=USART3_RX
PG11.Signal=LTDC_B3
PG15.Signal=FMC_SDNCAS
PD13.Signal=S_TIM4_CH2
PA15.GPIO_Label=PWM_DISPLAY
PF12.Signal=FMC_A6
PE13.Signal=FMC_D10_DA10
PI5.Signal=LTDC_B5
PI0.Signal=LTDC_G5
PF11.Signal=FMC_SDNRAS
PE4.Signal=LTDC_B0
PD7.GPIO_Label=HEX_1
PD13.GPIO_Label=PWM_RLED
PA6.Signal=ADCx_IN6
PC14/OSC32_IN.Signal=RCC_OSC32_IN
PD5.GPIO_Label=HEX_4
PA15.Signal=S_TIM2_CH1_ETR
PF8.Signal=QUADSPI_BK1_IO0
PF5.Signal=FMC_A5
PH7.Signal=I2C3_SCL
PF0.Signal=FMC_A0
PD3.GPIO_Label=HEX_8
PE7.Signal=FMC_D4_DA4
PD6.Signal=LTDC_B2
PB4.Signal=SPI1_MISO
PG2.GPIO_Label=STATUS_LED
PA3.Signal=USART2_RX
PG7.Signal=LTDC_CLK
PH11.Signal=LTDC_R5
PG1.Signal=FMC_A11
PC4.Signal=FMC_SDNE0
PI10.Signal=LTDC_HSYNC
PD9.Signal=FMC_D14_DA14
PD5.Signal=GPIO_Input
PA13.Signal=SYS_JTMS-SWDIO
PF6.Signal=QUADSPI_BK1_IO3
PH8.Signal=I2C3_SDA
PF2.Signal=FMC_A2
PE11.Signal=FMC_D8_DA8
PA1.Signal=LTDC_R2
PG9.GPIO_Label=ACEL_NEN
PI9.Signal=LTDC_VSYNC
PH0/OSC_IN.Signal=RCC_OSC_IN
PD4.GPIO_Label=HEX_2
PF10.Signal=LTDC_DE
PI4.Signal=LTDC_B4
PI7.GPIO_Label=AUDIO_EN
PF15.Signal=FMC_A9
PF1.Signal=FMC_A1
PE6.Signal=LTDC_G1
PE0.Signal=FMC_NBL0
PE12.Signal=FMC_D9_DA9
PA2.Signal=USART2_TX
PD14.Signal=FMC_D0_DA0
PB3.Signal=SPI1_SCK
PA14.Signal=SYS_JTCK-SWCLK
PH3.Signal=LTDC_R1

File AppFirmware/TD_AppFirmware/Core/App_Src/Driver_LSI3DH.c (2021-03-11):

/** ****************************************************************************************************
 * @file 			PWM_AccelerometerTaskSupport.c
 * @brief			This is the Header file provides driver api functions for chip LSI3DH
 * ****************************************************************************************************
 * @author			Hab S. Collector \n
 * Last Edited By:	Hab S. Collector \n
 *
 * @date			3/9/21 \n
 * @version       	See Main_Support.h: FIRMWARE_REV_MAJOR, FIRMWARE_REV_MINOR
 *
 * @param Development_Environment \n
 * Hardware:		STM32F746IGT6 \n
 * IDE:             STM32CubeIDE, VER 1.5.1 \n
 * Compiler:        GCC \n
 * Editor Settings: 1 Tab = 4 Spaces, Recommended Courier New 11
 *
 * @note            This file provides the driver API for chip LSI3DH - 3 Axis Accelerometer
 * 					The chip is interface on SPI1
 *
 *
 * 					This is an embedded application
 *		            It will be necessary to consult the reference documents to fully understand the code
 *                  It is suggested that the documents be reviewed in the order shown.
 *			          IMR Technology Demonstrator Schematic: IMR002S REV 1
 *				      IMR Technology Demonstrator Schematic: IMR002S REV 1
 *
 * @copyright		IMR Engineering
 * **************************************************************************************************** */

#include "Driver_LSI3DH.h"
#include "spi.h"
#include "math.h"


/*******************************************************************************************************
* @brief Performs an access of the LIS3DH_REGISTER_WHO_AM_I in search of a known response.  A read to said
* register is performed by writting the register value then reading the response.  If the IC is operational
* and online it will respond with its ID, if not response will not match
*
* @date				3/9/21 \n
* @author 			Hab S. Collector \n
* Last Edited By:  	Hab S. Collector \n
*
* @note LIS3DH connected via SPI1
*
* @param void
* @return True or False
*
* STEP 1: Perform Register Access for reading
* STEP 2: Read the register contents, compare and return
****************************************************************************************************** */
bool_t isAccelerometerOnLine(void)
{
	uint8_t RegisterAddress = LIS3DH_REGISTER_WHO_AM_I;
	uint8_t WhoAmI_Response = 22;
	HAL_StatusTypeDef CallStatus;

	// STEP 1: Perform Register Access for reading
	LIS3DH_CS_ENABLE();
	RegisterAddress |= LIS3DH_READ_OPERATION;
	CallStatus = HAL_SPI_Transmit(&hspi1, &RegisterAddress, 1, LIS3DH_SPI_BLOCK_TIMEOUT);
	if (CallStatus != HAL_OK)
		return(FALSE);

	// STEP 2: Read the register contents, compare and return
	CallStatus = HAL_SPI_Receive(&hspi1, &WhoAmI_Response, 1, LIS3DH_SPI_BLOCK_TIMEOUT);
	LIS3DH_CS_DISABLE();
	if ((WhoAmI_Response != LIS3DH_WHO_AM_I_VALUE) || (CallStatus != HAL_OK))
		return(FALSE);
	else
		return(TRUE);
} // END OF isAccelerometerOnLine



/*******************************************************************************************************
* @brief Read of LIS3DH register value.  Register is read and return by pointer
*
* @date				3/9/21 \n
* @author 			Hab S. Collector \n
* Last Edited By:  	Hab S. Collector \n
*
* @note LIS3DH connected via SPI1
*
* @param Register Address, Pointer to Value Read, Number of bytes to read
* @return True or False on read success
*
* STEP 1: Perform Register Access for reading
* STEP 2: Read the register contents and return
****************************************************************************************************** */
bool_t readAccelerometerRegister(uint8_t RegisterAddress, uint8_t *ReadValue, uint8_t BytesToRead)
{
	HAL_StatusTypeDef CallStatus;

	// STEP 1: Perform Register Access for reading
	RegisterAddress |= LIS3DH_READ_OPERATION;
	LIS3DH_CS_ENABLE();
	CallStatus = HAL_SPI_Transmit(&hspi1, &RegisterAddress, 1, LIS3DH_SPI_BLOCK_TIMEOUT);
	if (CallStatus != HAL_OK)
		return(FALSE);

	//STEP 2: Read the register contents and return
	CallStatus = HAL_SPI_Receive(&hspi1, ReadValue, BytesToRead, LIS3DH_SPI_BLOCK_TIMEOUT);
	LIS3DH_CS_DISABLE();
	if (CallStatus != HAL_OK)
		return(FALSE);
	else
		return(TRUE);
} // END OF readAccelerometerRegister



/*******************************************************************************************************
* @brief Write buffer to register.  The buffer contains the data to be written with the register address
* as the starting index of the buffer
*
* @date				3/9/21 \n
* @author 			Hab S. Collector \n
* Last Edited By:  	Hab S. Collector \n
*
* @note LIS3DH connected via SPI1
*
* @param Write buffer contents, Number of bytes to write
* @return True or False on write success
*
* STEP 1: Transmit buffer contents return success status
****************************************************************************************************** */
bool_t writeAccelerometerRegister(uint8_t *WriteBuffer, uint8_t BufferLength)
{

	HAL_StatusTypeDef CallStatus;

	LIS3DH_CS_ENABLE();
	CallStatus = HAL_SPI_Transmit(&hspi1, WriteBuffer, BufferLength, LIS3DH_SPI_BLOCK_TIMEOUT);
	LIS3DH_CS_DISABLE();
	if (CallStatus != HAL_OK)
		return(FALSE);
	else
		return(TRUE);

} // END OF writeAccelerometerRegister
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

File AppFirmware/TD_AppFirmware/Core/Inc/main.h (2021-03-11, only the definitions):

#define WIFI_EN_Pin GPIO_PIN_0
#define WIFI_EN_GPIO_Port GPIOA
#define TOUCH_IRQ_Pin GPIO_PIN_6
#define TOUCH_IRQ_GPIO_Port GPIOH
#define TOUCH_NRST_Pin GPIO_PIN_9
#define TOUCH_NRST_GPIO_Port GPIOH
#define PWM_GLED_Pin GPIO_PIN_12
#define PWM_GLED_GPIO_Port GPIOD
#define PWM_RLED_Pin GPIO_PIN_13
#define PWM_RLED_GPIO_Port GPIOD
#define STATUS_LED_Pin GPIO_PIN_2
#define STATUS_LED_GPIO_Port GPIOG
#define OTG_FS_VUSB_NEN_Pin GPIO_PIN_8
#define OTG_FS_VUSB_NEN_GPIO_Port GPIOA
#define DISPLAY_EN_Pin GPIO_PIN_1
#define DISPLAY_EN_GPIO_Port GPIOI
#define PWM_DISPLAY_Pin GPIO_PIN_15
#define PWM_DISPLAY_GPIO_Port GPIOA
#define HEX_8_Pin GPIO_PIN_3
#define HEX_8_GPIO_Port GPIOD
#define HEX_2_Pin GPIO_PIN_4
#define HEX_2_GPIO_Port GPIOD
#define HEX_4_Pin GPIO_PIN_5
#define HEX_4_GPIO_Port GPIOD
#define HEX_1_Pin GPIO_PIN_7
#define HEX_1_GPIO_Port GPIOD
#define ACEL_NEN_Pin GPIO_PIN_9
#define ACEL_NEN_GPIO_Port GPIOG
#define PWR_5V_EN_Pin GPIO_PIN_13
#define PWR_5V_EN_GPIO_Port GPIOG
#define AUDIO_EN_Pin GPIO_PIN_7
#define AUDIO_EN_GPIO_Port GPIOI

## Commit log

2020-11-11 Initial commit of Technology Demonstrator Project
    [AudioAndWifi.SchDoc, LCD_TouchBackLight.SchDoc, MC_Port Pin Assignment Table.xlsx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]
2020-11-13 Progress with schematic: all pages entered
    [AudioAmp.SchDoc, AudioAndWifi.SchDoc, LCD_TouchBackLight.SchDoc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]
2020-11-13 Initial connect before Schematic Compile
    [LCD_TouchBackLight.SchDoc, MainController.SchDoc, MainControllerPower.SchDoc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]
2020-11-24 Created Project PcbLib Fix corrupted IMR_Lib.PcbLib
    [10VSON.STEP, 1206.step, 14VSON.step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]
2020-11-25 All corrected models placed in PCB Created Project Schematic Lib TechDemo.SchLib
    [LCD_TouchBackLight.SchDoc, Power.SchDoc, SerialInterface.SchDoc]
2020-12-05 All components placed to PCB Rough route of all SDRAM nets Rough route of all TFT LCD nets
    [AudioAmp.SchDoc, CAP_2312.step, CAP_TANT_C3216_1206.step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]
2020-12-06 All display nets routed - footprints corrupted
2020-12-06 Correct IMR_Lib Footprints and copy
2020-12-08 Routing progress made in page order Ultrasonic
    [MainController.SchDoc, UserInteractive.SchDoc]
2020-12-09 All major routes done - next to add 3v3
    [MainController.SchDoc, UserInteractive.SchDoc]
2020-12-09 Progress on DRC fixes
    [TechDemo.PrjPcb]
2020-12-11 DRC fixes - changes to 10VSON and 14VSON
    [Power.SchDoc, TitleBlock.SchDoc]
2020-12-11 DRC fixes, Clean up, Display moved off PCB
2020-12-13 Silk Clean up, Create Output Job, Add Drill Fab DRC Errors = 0, Just need to find and fix 7 warnings (maybe)
    [Bill of Materials-TechDemo.xlsx, IMR PRODUCTION BOM Purchase.xlsx, IMR PROTOTYPE BOM Purchase Cost.xlsx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]
2020-12-13 Changes to TitleBlock schematic, Minor BOM fixes
    [AudioAmp.SchDoc, Bill of Materials-TechDemo.xlsx, MainControllerPower.SchDoc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]
2020-12-16 Design review fixes and changes
    [AudioAmp.SchDoc, Bill of Materials-TechDemo.xlsx, LCD_TouchBackLight.SchDoc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]
2020-12-17 Add Test Points - Change net names for Mod TypeID
    [AudioAmp.SchDoc, LCD_TouchBackLight.SchDoc, MainController.SchDoc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]
2020-12-19 Fixed BOM net tie problem, Cleanup trace widths Added export STEP file
    [AudioAmp.SchDoc, Bill of Materials-TechDemo.xlsx, LCD_TouchBackLight.SchDoc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]
2020-12-20 Fixed U10 footprint, added outline Tsilk J1 Added footprint checkplots
    [AudioAmp.SchDoc, Bill of Materials-TechDemo.xlsx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]
2021-02-06 Major Commit: Test Hardware Firmware This commit adds the firmware to test hardware - all of the major components are working. 0-9 and A-E total tests are added.
    [Bill of Materials-TechDemo.xlsx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]
2021-02-13 AppFirmware has TouchGFX display working TestHardware has display sort of working - perhaps an issue with how I write to the memory buffer. But you can see the display work
    [TD_AppFirmware Debug.cfg, texts.xlsx]
2021-02-21 Fixed a bug. Display would not show reliably. Needs to have CPU ICache and CPU DCache enabled Also added configuration for: PWR_5V, WIFI_EN, AUDIO_AMP AND VUSB_PWR
    [MainSupport.c, TD_AppFirmware.ioc, main.h]
2021-03-02 Has working display with Text - Touch not working
    [texts.xlsx]
2021-03-04 First commit to have Display & Touch working - YES
    [texts.xlsx]
2021-03-04 Add Splash Screen, MainMenu, and clickable AD Icon
    [texts.xlsx]
2021-03-06 Adds the AD and PA screen navigation to project Does not include anything happeing with AD screen
    [texts.xlsx]
2021-03-09 Analog Digital Screen Working here. Some additions for the PWM Accelerometer screen are included but just started none of it does anything
    [texts.xlsx]
2021-03-11 Screen_PAPresenter is working. Includes Screen_AD previously working Merge to master and create a new branch from here
    [texts.xlsx]
2021-03-21 Addedd Code for ESP8266 and web page HTML Implemented Wifi Access Point Receives two inputs from hardware Transmits On / Off for Red and Green LEDs
2021-03-22 Wifi Task Working and ready for pull request Includes the ESP8266 Code for Wifi Access Point Operation Task covers data exchange between websie and Tech Demo
    [texts.xlsx]
2021-04-11 Rev 2 Hardware design in progress Changed Document Number to IMR_004 Aobut 1/2 completed with hardware changes (schematic and layout)
    [AudioAmp.SchDoc, LCD_TouchBackLight.SchDoc, MainController.SchDoc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]
2021-04-13 Changes to power, pull-ups, Wifi in porgress
    [Bill of Materials-TechDemo.xlsx, LCD_TouchBackLight.SchDoc, MainController.SchDoc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]
2021-04-15 More changes to both PCB and SCH Correct push button switch and made battery transparent Added Folder structure to ESP8266 Folder and verified it worked with ESP-12F
    [MainController.SchDoc, Power.SchDoc]
2021-04-15 All known hardware schematic and PCB changes made Ready for DRC fixes
    [LCD_TouchBackLight.SchDoc, Power.SchDoc, Wifi.SchDoc]
2021-04-16 Fixed DRC errors and added Test Point spare GPIO
    [MainController.SchDoc]
2021-04-16 Remove 1 extra test point. Plane cut out for Wifi
    [Power.SchDoc, TechDemo.PrjPcb]
2021-04-16 Rev 2 Output job created in review
    [Bill of Materials-TechDemo(Normal Build Variant of TechDemo).xlsx, Bill of Materials-TechDemo.xlsx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]
2021-04-17 Added feed back to audio amp / change audio CC cap Reviewd - this looks good for release
    [AudioAmp.SchDoc, Bill of Materials-TechDemo(Normal Build Variant of TechDemo).xlsx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]
2021-04-20 REV 2 PCB released for builds
    [TechDemo.PrjPcb]

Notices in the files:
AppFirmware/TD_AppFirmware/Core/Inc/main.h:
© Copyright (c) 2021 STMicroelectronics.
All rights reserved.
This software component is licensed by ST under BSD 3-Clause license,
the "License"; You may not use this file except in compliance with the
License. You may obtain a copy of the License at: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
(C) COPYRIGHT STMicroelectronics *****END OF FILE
